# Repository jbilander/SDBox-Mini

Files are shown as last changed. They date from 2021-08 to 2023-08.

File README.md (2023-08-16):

# SDBox Mini for Amiga
SDBox in a standard DB25 plastic shell
***
Rev. 2B <br />
<a href="images/SDBox-mini_pic20.jpg">
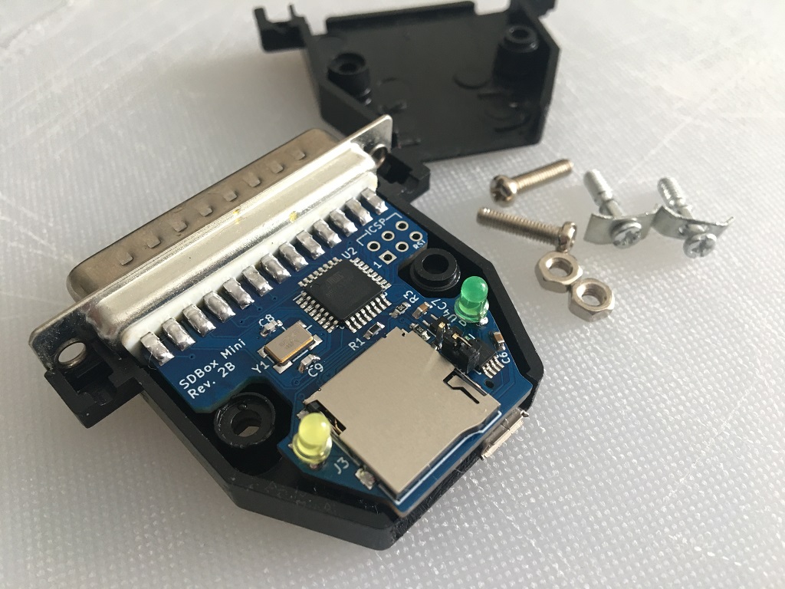
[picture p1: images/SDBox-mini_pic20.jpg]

</a>
<a href="images/SDBox-mini_pic21.jpg">
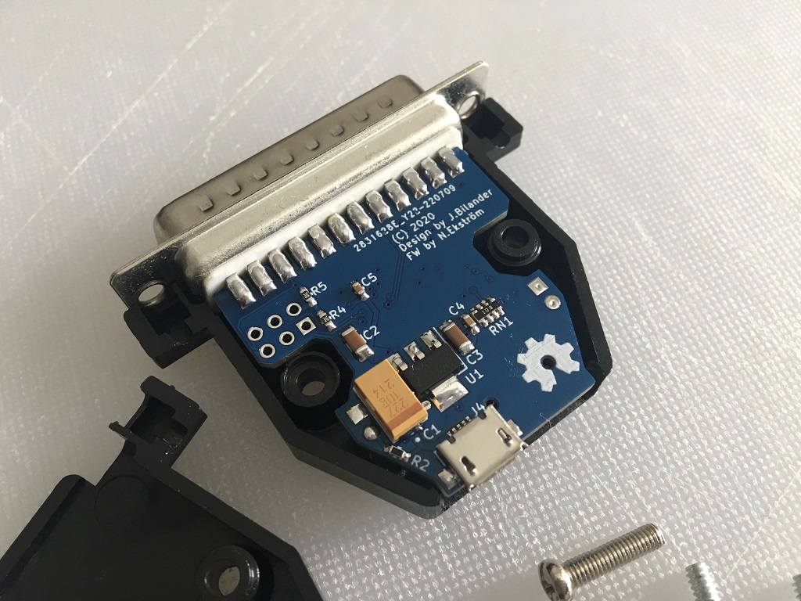
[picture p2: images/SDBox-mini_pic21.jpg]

</a>
<a href="images/SDBox-mini_pic22.jpg">
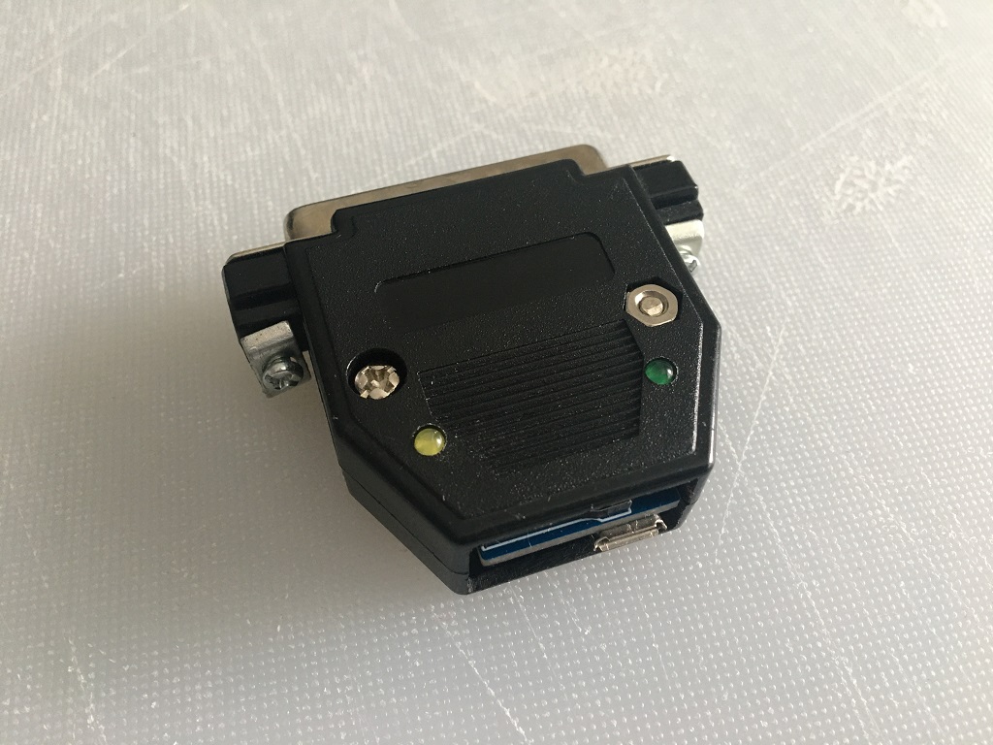
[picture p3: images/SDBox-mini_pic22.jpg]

</a>
<br />
Video:<br />
https://drive.google.com/file/d/1fLwmIyUeHZX4sln5bpJfz5QkDGD-QTOf/view?usp=sharing
<br />
<br />
+5V taken from floppy port with this USB-C dongle<br />
https://github.com/jbilander/Amiga_DB23_to_USB_C_power_only_adapter
***
Rev. 2A <br />
<a href="images/SDBox-mini_pic4.jpg">
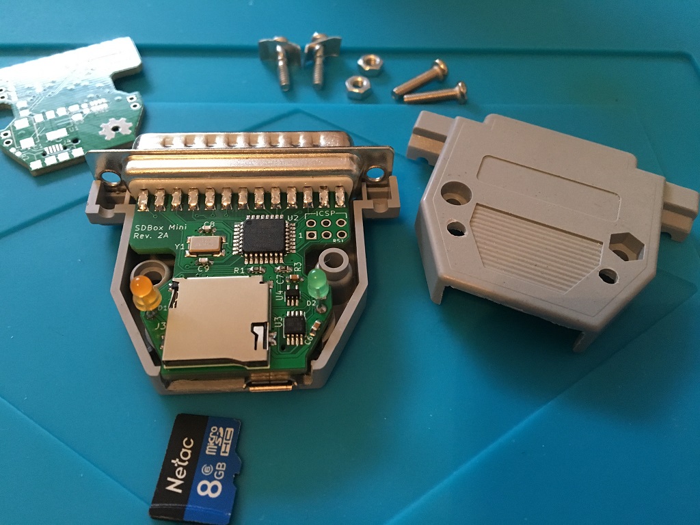
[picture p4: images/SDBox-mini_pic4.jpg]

</a>
<a href="images/SDBox-mini_pic5.jpg">
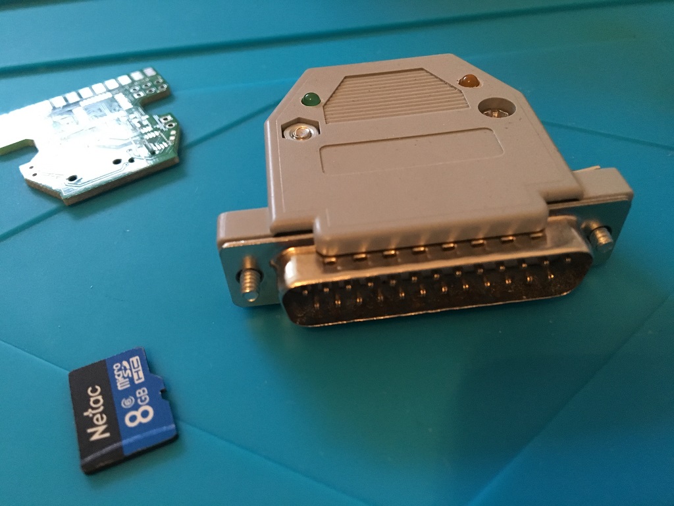
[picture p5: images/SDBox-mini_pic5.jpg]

</a>
<br />
<a href="images/SDBox-mini_pic1.png">
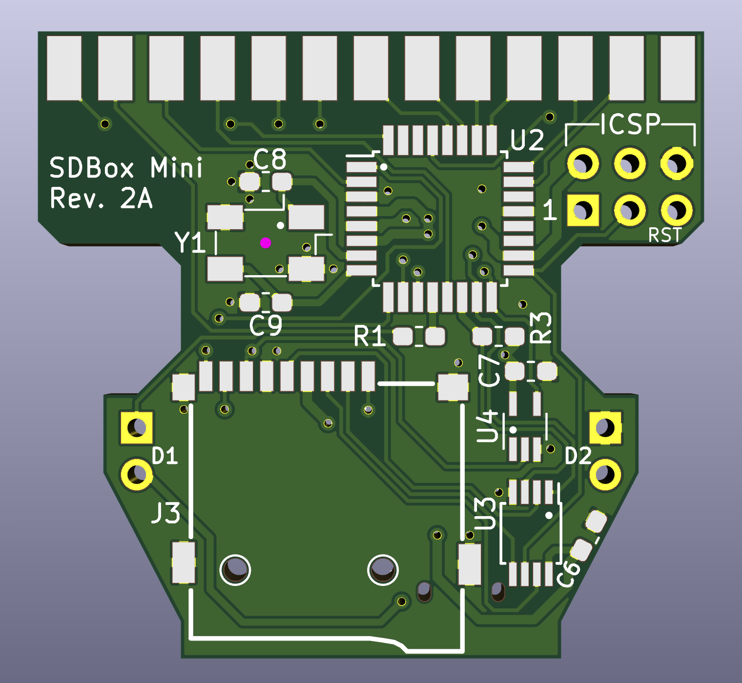
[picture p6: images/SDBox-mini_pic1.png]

</a>
<a href="images/SDBox-mini_pic2.png">
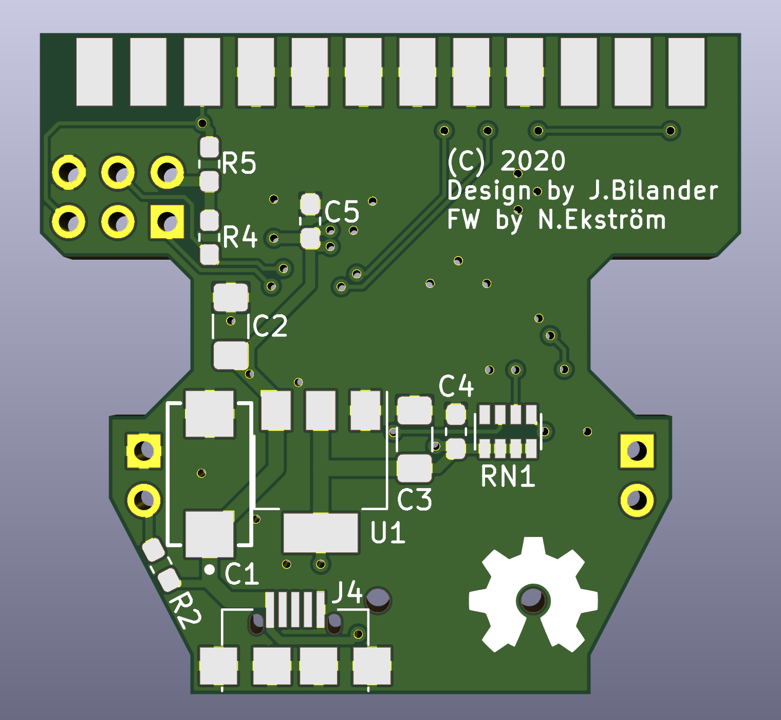
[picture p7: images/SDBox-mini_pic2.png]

</a>
<a href="images/SDBox-mini_pic3.png">
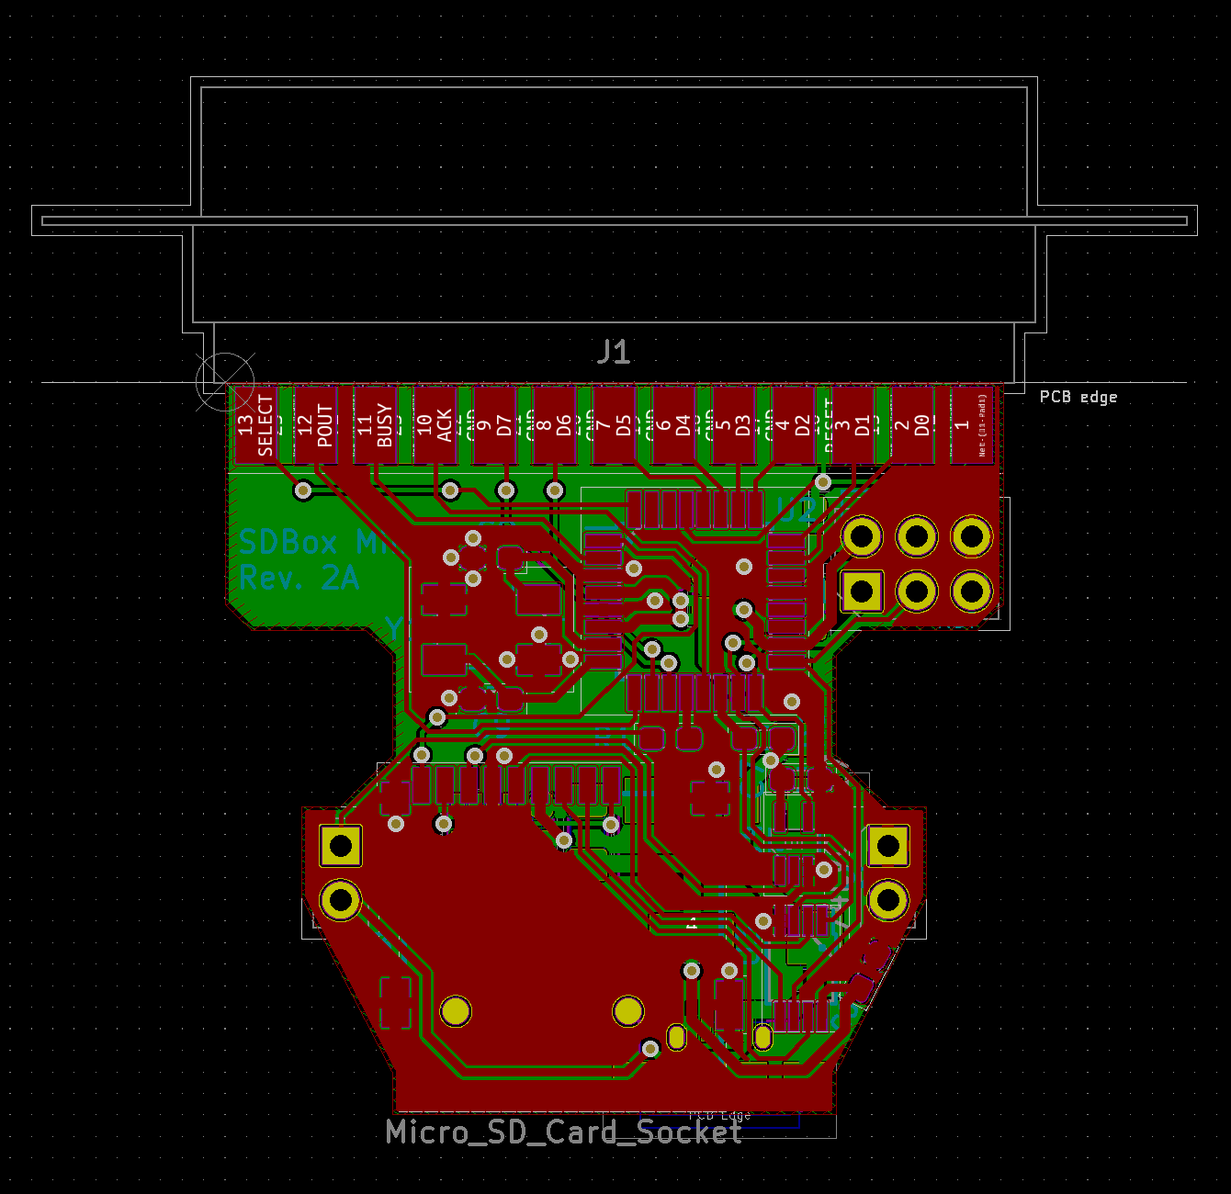
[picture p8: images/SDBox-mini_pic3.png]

</a>

***
This hardware uses the firmware written by Niklas Ekström, available here... <br />
https://github.com/niklasekstrom/amiga-par-to-spi-adapter

...or use my fork if you also want the Activity LED to blink (it also includes a batch-script `flashSDBoxMini.bat` for flashing the Mini) <br />
https://github.com/jbilander/amiga-par-to-spi-adapter

***
Connecting the Arduino to program the SDBox Mini

    (Programmer)
    Arduino as ISP - SDBox Mini 
    ------------------------------------
    D13 (SPI) SCK  - Pin 3 (ICSP) SCK
    D12 (SPI) MISO - Pin 1 (ICSP) MISO
    D11 (SPI) MOSI - Pin 4 (ICSP) MOSI
    D10 (SPI) SS   - Pin 5 (ICSP) /RESET
              5V   - Pin 2 VCC
              GND  - Pin 6 GND

On the Nano V3 the pins on the ICSP-header can be utilized connected like below. There is no need to solder an ICSP-header on the mini, you can just hold the connector against the footprint while programming.

<a href="images/connect_nano_ICSP_to_SDBox-mini.jpg">
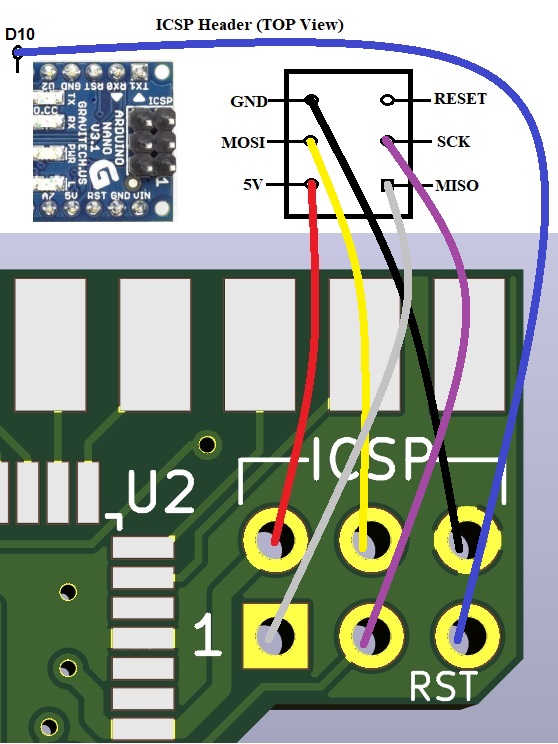
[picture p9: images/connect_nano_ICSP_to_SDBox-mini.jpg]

</a>
<a href="images/SDBox-mini_pic8.jpg">
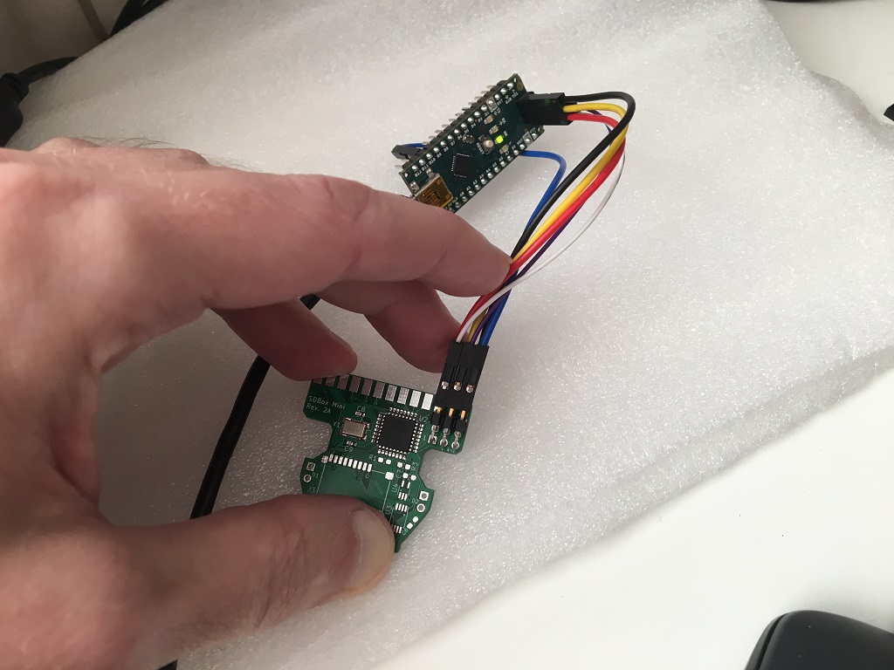
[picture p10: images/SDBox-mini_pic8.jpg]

</a>

***

To use the Arduino Nano as ISP it first has to be flashed with the ArduinoISP-sketch which is available under `File->Examples` in the Arduino IDE, or you can use the attached batch-script `flash_Arduino_as_ISP.bat` and binary hex `ArduinoISP.ino.arduino_standard.hex` I have put them in a zip-file under Releases `ArduinoISP.zip`. Alter the com port in the script file to suit your machine and execute it from a command-prompt. Now you are ready to flash the SDBox-Mini via the Arduino.

***

### Flash the SDBox Mini using the Arduino as ISP
This requires that you already have built the `main.hex` file in the `avr`-folder, then execute `flashSDBoxMini.bat` from a command prompt:
<details>
<summary>

    C:\Users\Jorgen\Projects\amiga-par-to-spi-adapter\avr>flashSDBoxMini.bat

</summary>

```
C:\Users\Jorgen\Projects\amiga-par-to-spi-adapter\avr>"C:\Program Files (x86)\Arduino\hardware\tools\avr/bin/avrdude" -C "C:\Program Files (x86)\Arduino\hardware\tools\avr/etc/avrdude.conf" -v -pm328p -cstk500v1 -PCOM4 -b19200 -Uflash:w:main.hex:i -Ulfuse:w:0xe6:m -Uhfuse:w:0xdf:m -Uefuse:w:0xfc:m

avrdude: Version 6.3-20190619
         Copyright (c) 2000-2005 Brian Dean, http://www.bdmicro.com/
         Copyright (c) 2007-2014 Joerg Wunsch

         System wide configuration file is "C:\Program Files (x86)\Arduino\hardware\tools\avr/etc/avrdude.conf"

         Using Port                    : COM4
         Using Programmer              : stk500v1
         Overriding Baud Rate          : 19200
         AVR Part                      : ATmega328P
         Chip Erase delay              : 9000 us
         PAGEL                         : PD7
         BS2                           : PC2
         RESET disposition             : dedicated
         RETRY pulse                   : SCK
         serial program mode           : yes
         parallel program mode         : yes
         Timeout                       : 200
         StabDelay                     : 100
         CmdexeDelay                   : 25
         SyncLoops                     : 32
         ByteDelay                     : 0
         PollIndex                     : 3
         PollValue                     : 0x53
         Memory Detail                 :

                                  Block Poll               Page                       Polled
           Memory Type Mode Delay Size  Indx Paged  Size   Size #Pages MinW  MaxW   ReadBack
           ----------- ---- ----- ----- ---- ------ ------ ---- ------ ----- ----- ---------
           eeprom        65    20     4    0 no       1024    4      0  3600  3600 0xff 0xff
           flash         65     6   128    0 yes     32768  128    256  4500  4500 0xff 0xff
           lfuse          0     0     0    0 no          1    0      0  4500  4500 0x00 0x00
           hfuse          0     0     0    0 no          1    0      0  4500  4500 0x00 0x00
           efuse          0     0     0    0 no          1    0      0  4500  4500 0x00 0x00
           lock           0     0     0    0 no          1    0      0  4500  4500 0x00 0x00
           calibration    0     0     0    0 no          1    0      0     0     0 0x00 0x00
           signature      0     0     0    0 no          3    0      0     0     0 0x00 0x00

         Programmer Type : STK500
         Description     : Atmel STK500 Version 1.x firmware
         Hardware Version: 2
         Firmware Version: 1.18
         Topcard         : Unknown
         Vtarget         : 0.0 V
         Varef           : 0.0 V
         Oscillator      : Off
         SCK period      : 0.1 us

avrdude: AVR device initialized and ready to accept instructions

Reading | ################################################## | 100% 0.07s

avrdude: Device signature = 0x1e950f (probably m328p)
avrdude: safemode: lfuse reads as E6
avrdude: safemode: hfuse reads as DF
avrdude: safemode: efuse reads as FC
avrdude: NOTE: "flash" memory has been specified, an erase cycle will be performed
         To disable this feature, specify the -D option.
avrdude: erasing chip
avrdude: reading input file "main.hex"
avrdude: writing flash (496 bytes):

Writing | ################################################## | 100% 0.68s

avrdude: 496 bytes of flash written
avrdude: verifying flash memory against main.hex:
avrdude: load data flash data from input file main.hex:
avrdude: input file main.hex contains 496 bytes
avrdude: reading on-chip flash data:

Reading | ################################################## | 100% 0.44s

avrdude: verifying ...
avrdude: 496 bytes of flash verified
avrdude: reading input file "0xe6"
avrdude: writing lfuse (1 bytes):

Writing | ################################################## | 100% 0.03s

avrdude: 1 bytes of lfuse written
avrdude: verifying lfuse memory against 0xe6:
avrdude: load data lfuse data from input file 0xe6:
avrdude: input file 0xe6 contains 1 bytes
avrdude: reading on-chip lfuse data:

Reading | ################################################## | 100% 0.02s

avrdude: verifying ...
avrdude: 1 bytes of lfuse verified
avrdude: reading input file "0xdf"
avrdude: writing hfuse (1 bytes):

Writing | ################################################## | 100% 0.02s

avrdude: 1 bytes of hfuse written
avrdude: verifying hfuse memory against 0xdf:
avrdude: load data hfuse data from input file 0xdf:
avrdude: input file 0xdf contains 1 bytes
avrdude: reading on-chip hfuse data:

Reading | ################################################## | 100% 0.02s

avrdude: verifying ...
avrdude: 1 bytes of hfuse verified
avrdude: reading input file "0xfc"
avrdude: writing efuse (1 bytes):

Writing | ################################################## | 100% 0.03s

avrdude: 1 bytes of efuse written
avrdude: verifying efuse memory against 0xfc:
avrdude: load data efuse data from input file 0xfc:
avrdude: input file 0xfc contains 1 bytes
avrdude: reading on-chip efuse data:

Reading | ################################################## | 100% 0.02s

avrdude: verifying ...
avrdude: 1 bytes of efuse verified

avrdude: safemode: lfuse reads as E6
avrdude: safemode: hfuse reads as DF
avrdude: safemode: efuse reads as FC
avrdude: safemode: Fuses OK (E:FC, H:DF, L:E6)

avrdude done.  Thank you.

C:\Users\Jorgen\Projects\amiga-par-to-spi-adapter\avr>

```
</details>

***

### Connecting a RPi4 to program the SDBox Mini

<br />
Warning!<br />
Connection of a GPIO to a voltage higher than 3.3V will likely destroy the GPIO block within the SoC.<br /><br />
I used my <a href="https://github.com/jbilander/Logic-level-converter-board">Logic level converter board</a> in between the devices and powered from the RPi's +5V 
<br />
<br />
<a href="images/SDBox-mini_RPi4-GPIO-Programming.jpg">
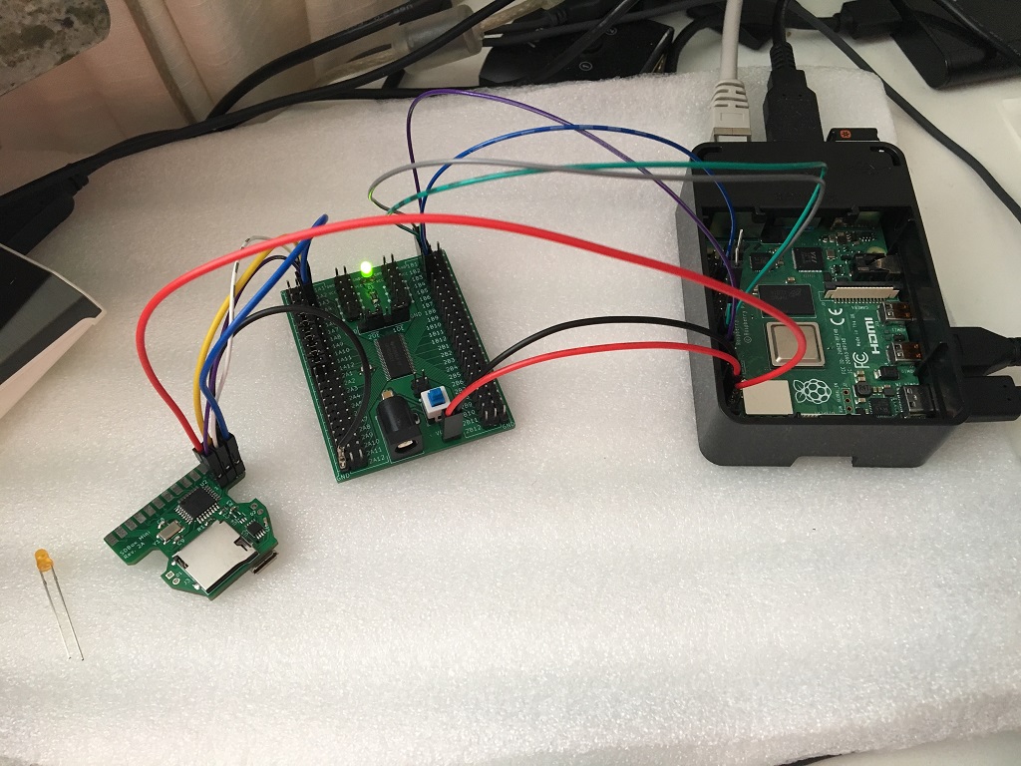
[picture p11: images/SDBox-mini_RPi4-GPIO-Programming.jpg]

</a>
<a href="images/RPi4-GPIO-Pinout.jpg">
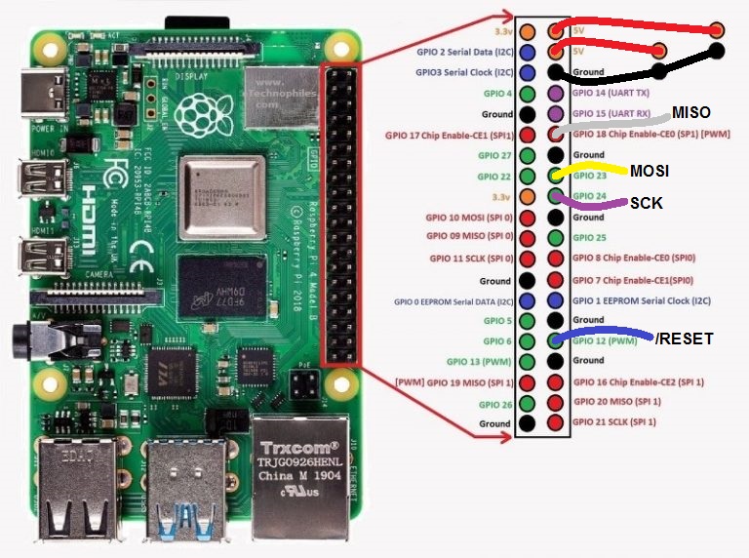
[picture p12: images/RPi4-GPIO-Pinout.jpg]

</a>
<br />
First install avrdude:

    sudo apt install avrdude

Now copy the default config file to a new file under /home/pi

    cp /etc/avrdude.conf ~/avrdude_gpio.conf
    
Add this entry last in the file using your editor (vim or nano) and save the file:

    #------------------------------------------------------------
    # Linux GPIO configuration for avrdude
    # Change the lines below to the GPIO pins connected to the AVR
    #------------------------------------------------------------
    programmer
        id        = "pi_1";
        desc      = "Use the Linux sysfs interface to bitbang GPIO lines";
        type      = "linuxgpio";
        reset     = 12;
        sck       = 24;
        mosi      = 23;
        miso      = 18;
    ;

Now cd into /home/pi and make the script-file executable:

    chmod 755 ./flashSDBoxMini.sh

With all jumper-wires connected and `main.hex` built, run the script `flashSDBoxMini.sh` (OR type the line below and hit enter)

    sudo avrdude -C ~/avrdude_gpio.conf -c pi_1 -v -p m328p -Uflash:w:main.hex:i -Ulfuse:w:0xe6:m -Uhfuse:w:0xdf:m -Uefuse:w:0xfc:m

<details>
<summary>

    pi@raspberrypi:~ $ ./flashSDBoxMini.sh

</summary>

```
avrdude: Version 6.3-20171130
         Copyright (c) 2000-2005 Brian Dean, http://www.bdmicro.com/
         Copyright (c) 2007-2014 Joerg Wunsch

         System wide configuration file is "/home/pi/avrdude_gpio.conf"
         User configuration file is "/root/.avrduderc"
         User configuration file does not exist or is not a regular file, skipping

         Using Port                    : unknown
         Using Programmer              : pi_1
         AVR Part                      : ATmega328P
         Chip Erase delay              : 9000 us
         PAGEL                         : PD7
         BS2                           : PC2
         RESET disposition             : dedicated
         RETRY pulse                   : SCK
         serial program mode           : yes
         parallel program mode         : yes
         Timeout                       : 200
         StabDelay                     : 100
         CmdexeDelay                   : 25
         SyncLoops                     : 32
         ByteDelay                     : 0
         PollIndex                     : 3
         PollValue                     : 0x53
         Memory Detail                 :

                                  Block Poll               Page                       Polled
           Memory Type Mode Delay Size  Indx Paged  Size   Size #Pages MinW  MaxW   ReadBack
           ----------- ---- ----- ----- ---- ------ ------ ---- ------ ----- ----- ---------
           eeprom        65    20     4    0 no       1024    4      0  3600  3600 0xff 0xff
           flash         65     6   128    0 yes     32768  128    256  4500  4500 0xff 0xff
           lfuse          0     0     0    0 no          1    0      0  4500  4500 0x00 0x00
           hfuse          0     0     0    0 no          1    0      0  4500  4500 0x00 0x00
           efuse          0     0     0    0 no          1    0      0  4500  4500 0x00 0x00
           lock           0     0     0    0 no          1    0      0  4500  4500 0x00 0x00
           calibration    0     0     0    0 no          1    0      0     0     0 0x00 0x00
           signature      0     0     0    0 no          3    0      0     0     0 0x00 0x00

         Programmer Type : linuxgpio
         Description     : Use the Linux sysfs interface to bitbang GPIO lines
         Pin assignment  : /sys/class/gpio/gpio{n}
           RESET   =  12
           SCK     =  24
           MOSI    =  23
           MISO    =  18

avrdude: AVR device initialized and ready to accept instructions

Reading | ################################################## | 100% 0.00s

avrdude: Device signature = 0x1e950f (probably m328p)
avrdude: safemode: lfuse reads as E6
avrdude: safemode: hfuse reads as DF
avrdude: safemode: efuse reads as FC
avrdude: NOTE: "flash" memory has been specified, an erase cycle will be performed
         To disable this feature, specify the -D option.
avrdude: erasing chip
avrdude: reading input file "main.hex"
avrdude: writing flash (496 bytes):

Writing | ################################################## | 100% 0.11s

avrdude: 496 bytes of flash written
avrdude: verifying flash memory against main.hex:
avrdude: load data flash data from input file main.hex:
avrdude: input file main.hex contains 496 bytes
avrdude: reading on-chip flash data:

Reading | ################################################## | 100% 0.10s

avrdude: verifying ...
avrdude: 496 bytes of flash verified
avrdude: reading input file "0xe6"
avrdude: writing lfuse (1 bytes):

Writing | ################################################## | 100% 0.00s

avrdude: 1 bytes of lfuse written
avrdude: verifying lfuse memory against 0xe6:
avrdude: load data lfuse data from input file 0xe6:
avrdude: input file 0xe6 contains 1 bytes
avrdude: reading on-chip lfuse data:

Reading | ################################################## | 100% 0.00s

avrdude: verifying ...
avrdude: 1 bytes of lfuse verified
avrdude: reading input file "0xdf"
avrdude: writing hfuse (1 bytes):

Writing | ################################################## | 100% 0.00s

avrdude: 1 bytes of hfuse written
avrdude: verifying hfuse memory against 0xdf:
avrdude: load data hfuse data from input file 0xdf:
avrdude: input file 0xdf contains 1 bytes
avrdude: reading on-chip hfuse data:

Reading | ################################################## | 100% 0.00s

avrdude: verifying ...
avrdude: 1 bytes of hfuse verified
avrdude: reading input file "0xfc"
avrdude: writing efuse (1 bytes):

Writing | ################################################## | 100% 0.00s

avrdude: 1 bytes of efuse written
avrdude: verifying efuse memory against 0xfc:
avrdude: load data efuse data from input file 0xfc:
avrdude: input file 0xfc contains 1 bytes
avrdude: reading on-chip efuse data:

Reading | ################################################## | 100% 0.00s

avrdude: verifying ...
avrdude: 1 bytes of efuse verified

avrdude: safemode: lfuse reads as E6
avrdude: safemode: hfuse reads as DF
avrdude: safemode: efuse reads as FC
avrdude: safemode: Fuses OK (E:FC, H:DF, L:E6)

avrdude done.  Thank you.

pi@raspberrypi:~ $

```
</details>

***

### Caveats

One caveat to keep in mind when building and programming Rev.2A (the first revision of the Mini) is the flashing of the fw can't be done with U4 chip in place as it drives/conflicts with MISO on ICSP (In-Circuit Serial Programming). For Rev. 2B PCB use 74AHCT1G126 instead of 74LVC1G17, same package/footprint. This solves the flashing conflict problem. You put a Jumper-shunt on JP1 (on Rev 2B PCB) while flashing and remove it afterwards.

***

### Building SDBox Mini

Start with the 16 MHz Crystal, C8, C9 and the ATMega328P. 

<a href="images/SDBox-mini_pic6.jpg">
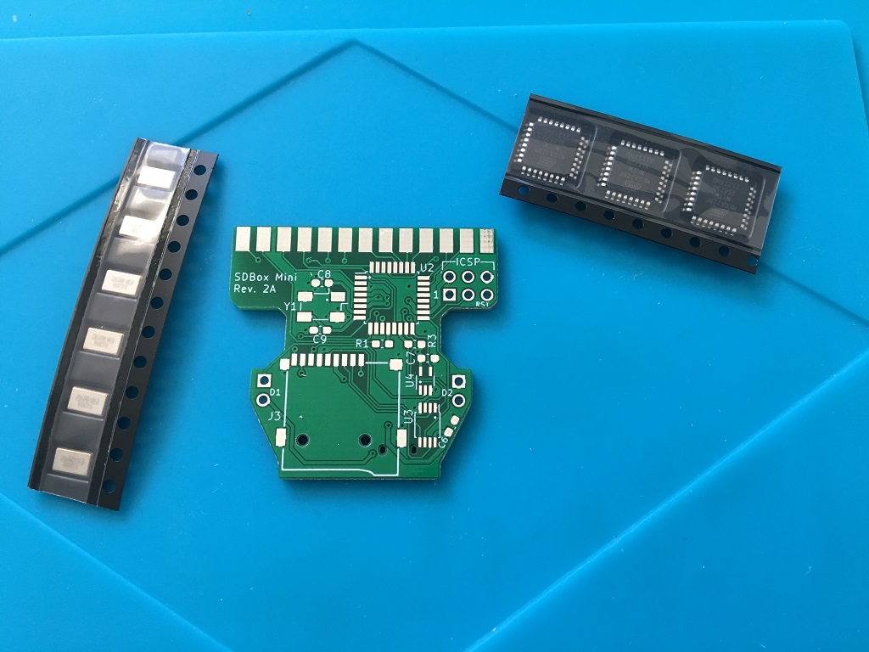
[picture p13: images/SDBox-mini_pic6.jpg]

</a>
<a href="images/SDBox-mini_pic7.jpg">
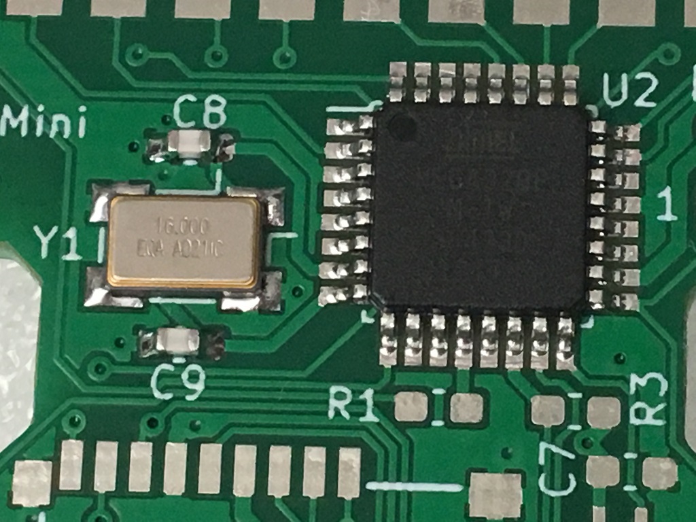
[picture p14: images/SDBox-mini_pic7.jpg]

</a>

***

At this point you should be able to flash the Firmware to the ATMega using either an Arduino as ISP or a Raspberry Pi.<br /><br />

Continue with the rest of the components on the front side, and then the back side. I usually pre-tin the C1 pads and use hot air to put the C1-Capacitor in place.
***

<a href="images/SDBox-mini_pic9.jpg">
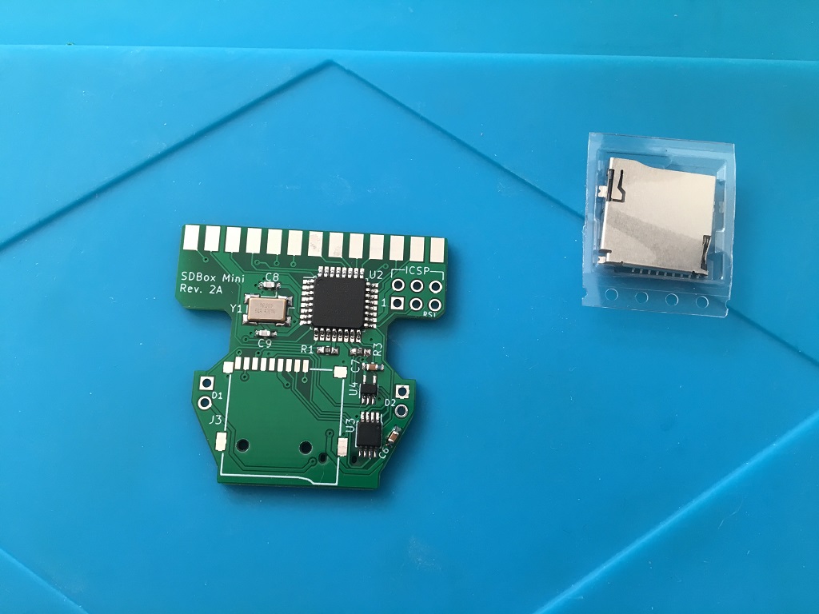
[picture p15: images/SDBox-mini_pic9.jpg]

</a>
<a href="images/SDBox-mini_pic10.jpg">
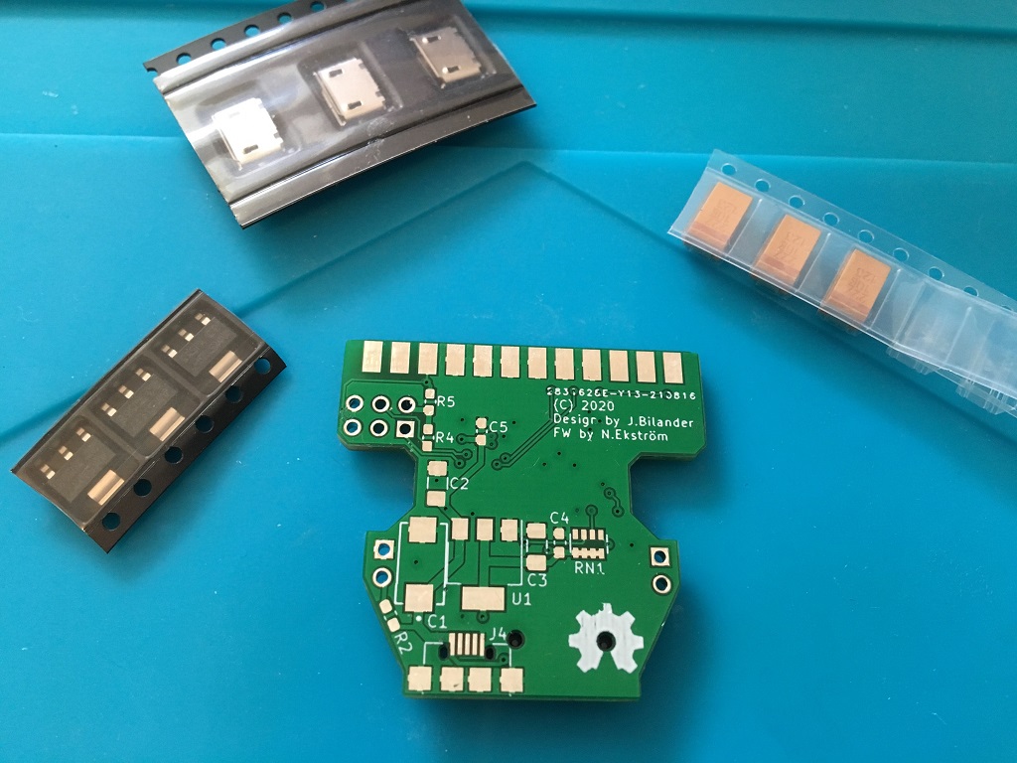
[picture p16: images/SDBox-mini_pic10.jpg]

</a>
<a href="images/SDBox-mini_pic11.jpg">
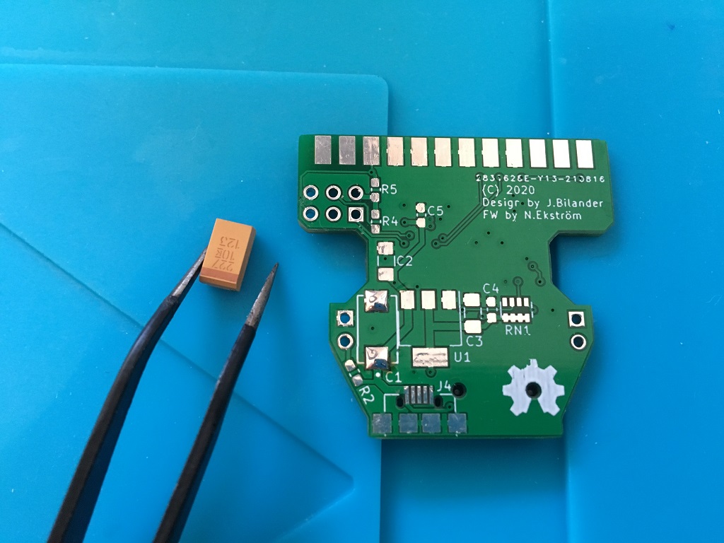
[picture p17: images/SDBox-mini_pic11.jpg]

</a>

***

Verify the Micro USB-jack and the voltage levels...

***

<a href="images/SDBox-mini_pic12.jpg">
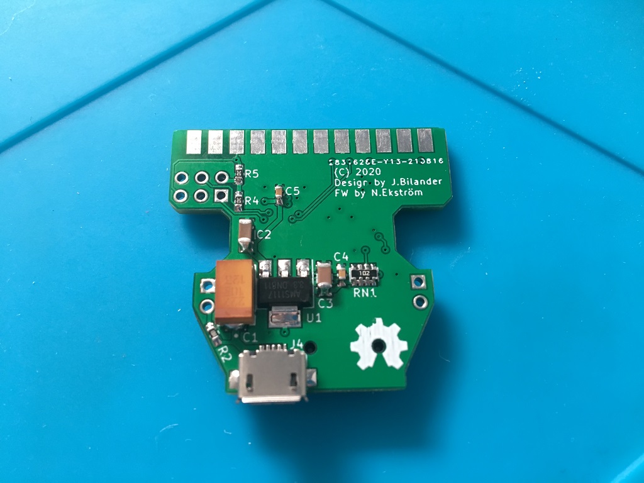
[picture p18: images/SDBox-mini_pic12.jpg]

</a>
<a href="images/SDBox-mini_pic13.jpg">
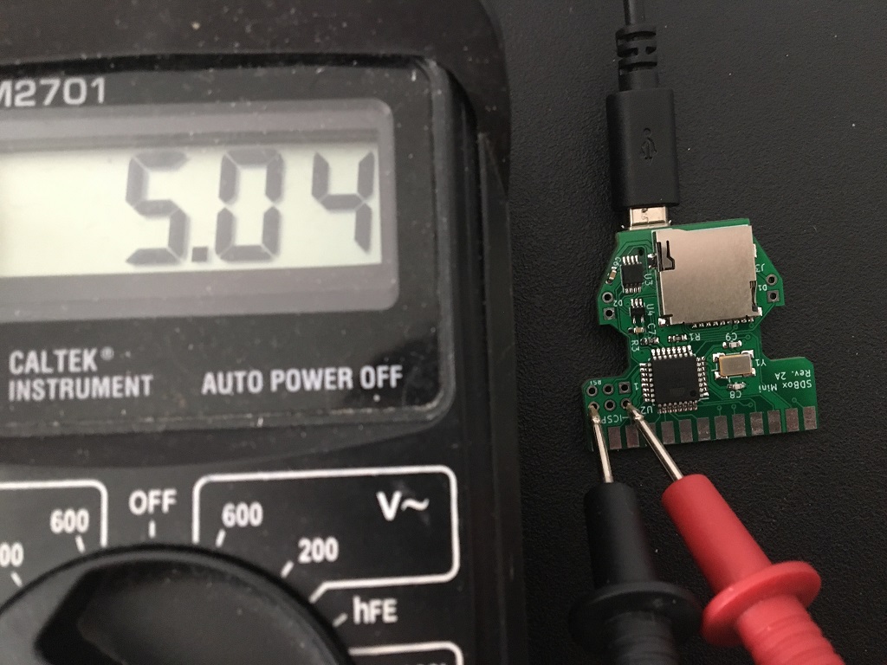
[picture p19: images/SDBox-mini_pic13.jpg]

</a>
<a href="images/SDBox-mini_pic14.jpg">
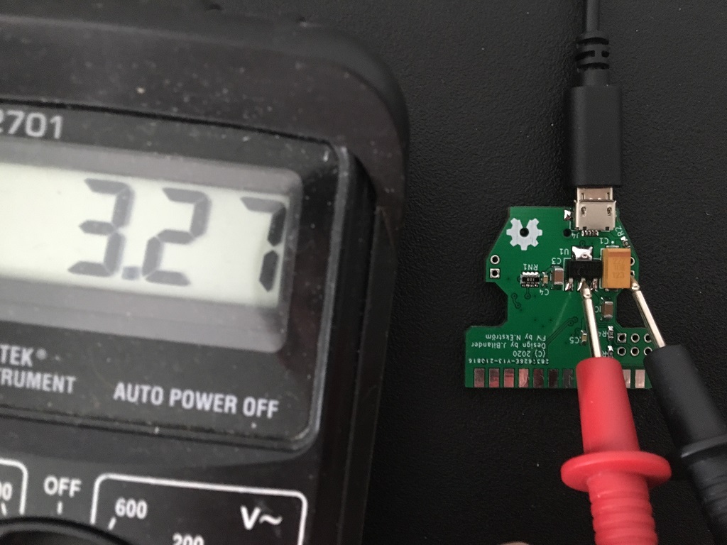
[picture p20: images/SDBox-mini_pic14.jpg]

</a>

***

Now it's time to drill the holes for the LEDs, begin with a 1 mm drill and then step up to 2 mm and finally 3 mm. Be very careful when drilling to get a nice clean 3mm hole, it's very easy to slip and the hole gets oval or offset.

***

<a href="images/SDBox-mini_pic15.jpg">
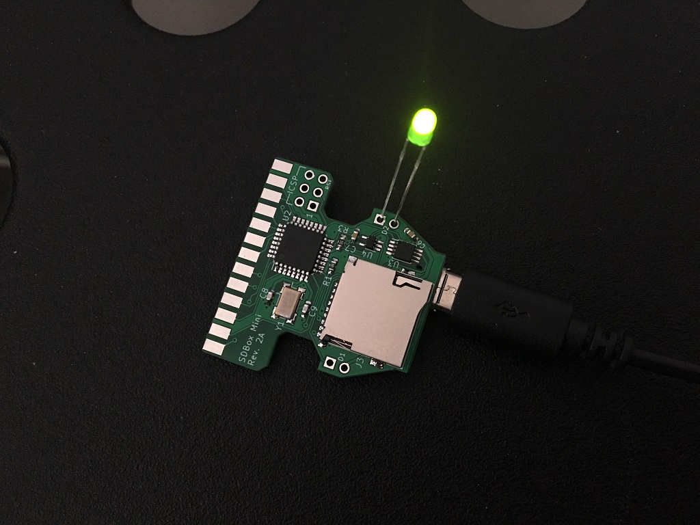
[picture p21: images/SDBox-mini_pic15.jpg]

</a>
<a href="images/SDBox-mini_pic16.jpg">
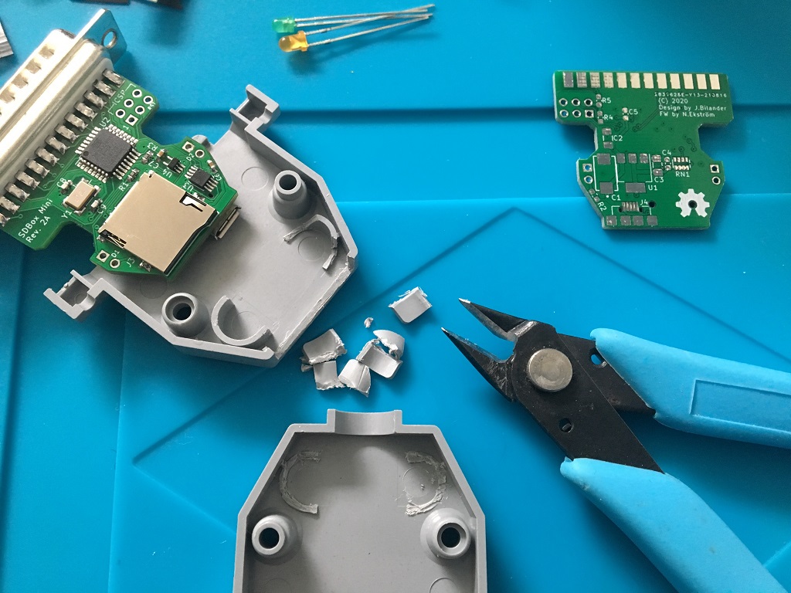
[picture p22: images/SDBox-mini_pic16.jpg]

</a>
<a href="images/SDBox-mini_pic17.jpg">
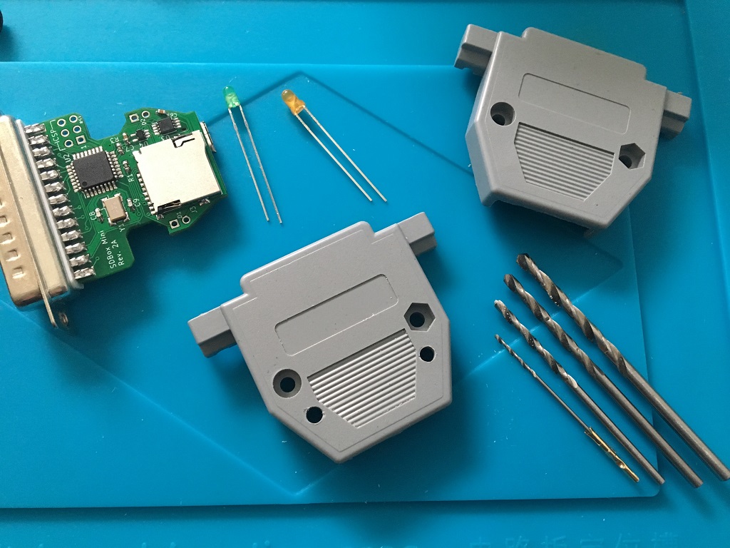
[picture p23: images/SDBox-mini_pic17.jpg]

</a>

***

Short video showing copying a 8 MB file from the HD to the SD-card on my A1200. +5V to power the SDBox I nicked from the floppy port DB23->microUSB (Howto make such a cable <a href="https://github.com/jbilander/SDBox-v2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">here</a> ).
<br />
Video:<br />
https://i.imgur.com/mF9Bp4C.mp4

***

<a href="images/SDBox-mini_pic4.jpg">

</a>
<a href="images/SDBox-mini_pic18.jpg">
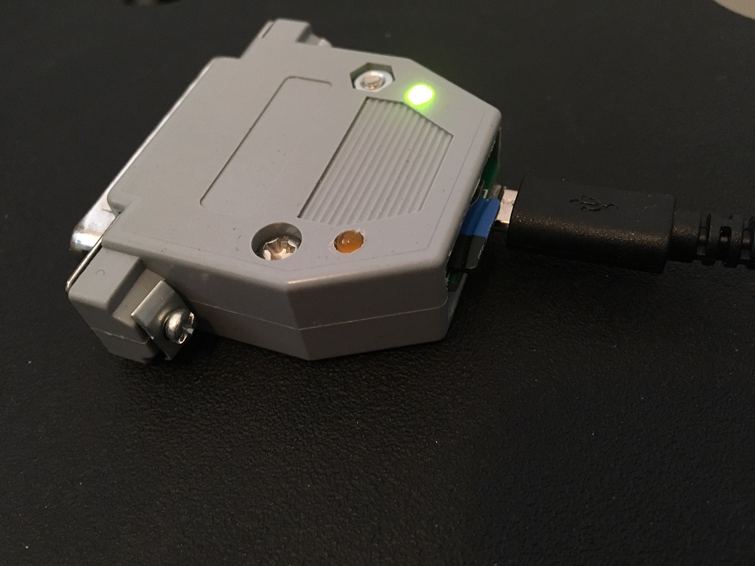
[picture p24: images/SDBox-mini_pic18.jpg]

</a>
<a href="images/SDBox-mini_pic19.jpg">
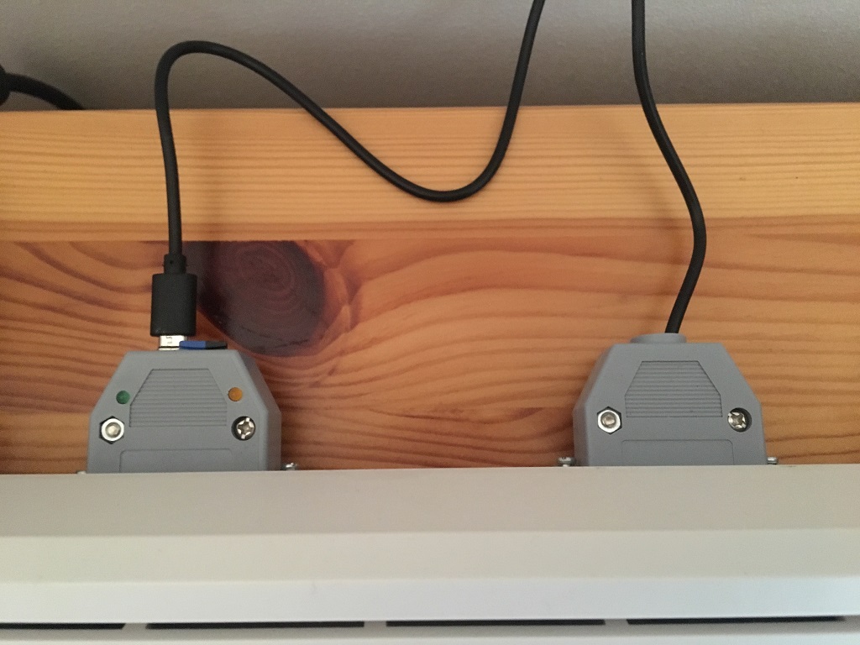
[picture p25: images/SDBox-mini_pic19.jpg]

</a>

***

### Amiga installation:

Download `Amiga.zip` from Releases.

* Put latest `fat95` into `L:`  (download from Aminet)
* Put `SD0` and `SD0.info` into `Devs:`  (from `Amiga.zip`)
* Put `spisd.device` into `Devs:` (from `Amiga.zip`)
* Put `Mount_SDCARD` and `Mount_SDCARD.info` anywhere on your HD or floppy disk.
* Put a FAT/FAT32 formatted MicroSD-card in the card reader (Max 4 GB partitioned).
* Double-click the `Mount_SDCARD` icon.

Disk icon should now appear on the Workbench screen.

***

Happy Hackin´

***
BOM Rev. 2B  (Same as 2A with the addition)
---------
Position  | Name/Value   | Package | Notes
-|-|-|-|
U4 | 74AHCT1G126 | 5-TSSOP, SC-70-5, SOT-353  (2.0 mm × 1.25mm) | Single non-inverting buffer 74AHCT1G126 (instead of 74LVC1G17) https://www.mouser.com/ProductDetail/Nexperia/74AHCT1G126GW125?qs=P62ublwmbi%252BsCpFPoi5fgw%3D%3D 
JP1 | 2.0mm two-pin header + jumper-shunt | |
R6 | 10k Ohm Resistor | 0603 SMD | Pull-up resistor for OE pin 1 of 74AHCT1G126

***

BOM Rev. 2A
---------
Position  | Name/Value   | Package | Notes
-|-|-|-|
U1 | LM1117-3.3 | SOT-223 | Low-Dropout Linear Regulator 3.3 Volt
U2 | ATMega328P-AU | TQFP-32_7x7mm_P0.8mm | 8-bit AVR Microcontroller with 32K Bytes In-System Programmable Flash
U3 | 74LVC3G17 | TSSOP-8_3x3mm_P0.65mm | Triple non-inverting Schmitt trigger with 5V tolerant input https://www.digikey.se/product-detail/en/nexperia-usa-inc/74LVC3G17DP-125/1727-5998-1-ND/2753830
U4 | 74LVC1G17 | 5-TSSOP, SC-70-5, SOT-353  (2.0 mm × 1.25mm) | Single non-inverting Schmitt trigger https://www.digikey.se/product-detail/en/nexperia-usa-inc/74LVC1G17GW-125/1727-4117-1-ND/1965408 For Rev. 2B PCB use 74AHCT1G126 instead of 74LVC1G17, same package/footprint: https://www.mouser.com/ProductDetail/Nexperia/74AHCT1G126GW125?qs=P62ublwmbi%252BsCpFPoi5fgw%3D%3D
J1 | D-Sub DB25 | DB25 Male connector with solder lugs | DB25 for Amiga parallel port
J2 | ICSP | PinHeader_2x03_P2.54mm_Vertical | Pin header _(MISO,VCC,SCK,MOSI,/RESET,GND)_ for flashing AVR via In-Circuit Serial Programming
J3 | Micro SD Card Holder | 9-pin Micro SD card slot connector | https://www.aliexpress.com/item/32802051702.html
J4 | Micro USB connector | USB Micro B SMT | For +5V Power only <br />https://www.aliexpress.com/item/32991869539.html
Y1 | Ceramic SMD quartz 16.0 MHz, LC 12 pF | 3 x 5 x 1 mm | For use with XTAL1, XTAL2 on AVR, e.g. https://www.reichelt.com/se/en/ceramic-smd-quartz-3-x-5-x-1-mm-16-0-mhz-16-000000-mj-p85005.html <br /> or <br /> https://www.mouser.se/ProductDetail/520-160-12-30B-AGMT
D1 (Optional) | LED 3mm | PinHeader_1x02_P2.54mm_Vertical, pin pitch 2.54 mm | SD Activity LED indicator, Diffused Orange / Amber, 1.8V-2.3V, 20-30 mA, 605-610nm
D2 (Optional) | LED 3mm | PinHeader_1x02_P2.54mm_Vertical, pin pitch 2.54 mm | Power LED indicator, Green Diffused T-1, 25 mcd, 565 nm, 2.2 V, 25 mA
R1 (Optional) | 150 Ohm Resistor | 0603 SMD, 200 mW | (Mandatory if D1 populated) Series resistor for D1 LED, adjust R-value to your type of LED and preferred brightness
R2 (Optional) | 150 Ohm Resistor | 0603 SMD, 200 mW | (Mandatory if D2 populated) Series resistor for D2 LED, adjust R-value to your type of LED and preferred brightness
R3 | 10k Ohm Resistor | 0603 SMD | Pull-up (to VCC) resistor for /SS
R4 (Optional) | 10k Ohm Resistor | 0603 SMD | Pull-up (to VCC) resistor for MOSI
R5 (Optional) | 10k Ohm Resistor | 0603 SMD | Pull-up (to VCC) resistor for /RESET
RN1 | CAY16-103J4LF RES ARRAY 4 Resistors 10k | 1206 SMD | https://www.digikey.se/product-detail/sv/bourns-inc/CAY16-103J4LF/CAY16-103J4LFCT-ND/
RN1 | | | Pull-up (to 3V3) for MISO_3V3
RN1 | | | Pull-up (to 3V3) for DAT1 pin 8 on MicroSD-holder
RN1 | | | Pull-up (to 3V3) for DAT2 pin 1 on MicroSD-holder
C1 | 220uF Capacitor | SMD-Tantalum, 4.3 x 7.3 x 2.8 mm | Capacitor for VIN +5V Power via USB https://www.reichelt.com/se/en/smd-tantalum-220-f-10v-125-c-t491d-220u-10-p206492.html
C2 | 10uF Capacitor | 1206 SMD | Capacitor (VCC) for Voltage regulator U1
C3 | 10uF Capacitor | 1206 SMD | Capacitor (3V3) for Voltage regulator U1
C4 | 0.1uF = 100nF Capacitor | 0603 SMD | Capacitor (3V3) for Voltage regulator U1
C5 | 0.1uF = 100nF Capacitor | 0603 SMD | Decoupling capacitor for U2
C6 | 0.1uF = 100nF Capacitor | 0603 SMD | Decoupling capacitor for U3
C7 | 0.1uF = 100nF Capacitor | 0603 SMD | Decoupling capacitor for U4
C8 | 16pF Capacitor | 0603 SMD | Capacitor for XTAL1 (Y1)
C9 | 16pF Capacitor | 0603 SMD | Capacitor for XTAL2 (Y1)
X | D-Sub DB25 | Two DB25 plastic shells with screws and nuts | Plastic hood cover x 2

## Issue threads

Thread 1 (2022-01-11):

Writing errors

Knuckles112, 2022-01-11:
First of all, thank you for this project. I assambled 2 boards flashing your firmware but I get errors writing to the SD (I have tried with various brands and partitions), reading is fine. Any ideas?
P.S. Tested on A500 and A1200

jbilander, 2022-01-11:
Hi, That's strange. I haven't seen any write errors on my A500 nor A1200. What is your configuration in terms of KS-version and WB? I have only tested on KS/WB 1.3 and 3.1 on A500/A1200. You can check/verify your CIA timings is ok with ATK (AmigaTestKit), link below:
https://github.com/keirf/Amiga-Stuff/releases

Things you could check if you have a logic analyser or oscilloscope:
Check logic levels on the D0-D7, SELECT, BUSY, POUT -lines. Perhaps pull-ups could/should be added.

I think VIH -- Minimum INPUT Voltage level to be considered a HIGH is 0.6*VCC equals around 3V on the ATMega328 when VCC is 5V.
https://learn.sparkfun.com/tutorials/logic-levels/all#arduino-logic-levels

Knuckles112, 2022-01-18:
Hello. I have already made all the measurements with the oscilloscope. Attached are the measurements taken on the Atmel in "MISO" and "MOSI" lines when there is read/write activity.
All other signals are HI at 5V and LO at 0V, but "MOSI" is the suspect because of its form.
I have already tried several different ATMEGA328 and ATMEGA328P with the same result.
All the resistors and components are installed, I have also tried without the optional pullups with the same result.
When I want to copy something from the Amiga to the SD I always get write errors and practically nothing is written to the SD.
MISO:
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
MOSI:
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

Thank you in advance.

niklasekstrom, 2022-01-18:
Interesting.

How fast can your oscilloscope sample signals (what is the max frequency)?

Do you have an accelerator in the A500?

Knuckles112, 2022-01-18:
-How fast can your oscilloscope sample signals (what is the max frequency)?
200Mhz / 1GSa/s
-Do you have an accelerator in the A500?
Yes, a TF534 but with the original processor and loading drivers from floppy I obtain the same write errors.
I have also tried it with an Amiga 1200, I always get the same writing problem.

niklasekstrom, 2022-01-18:
Can you zoom in more on the MOSI signal? The SPI bus should switch at 8 MHz, so the cycle time is 125 ns.

And perhaps measure both before and after U3?

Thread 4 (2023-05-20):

"Bad Number" issue

youenchene, 2023-05-20:
Hi,

Tx a lot for your work.

I just solder my first SDBox Mini and trying to make it work. (rev2b)

I compiled the firmware from this source : https://github.com/jbilander/amiga-par-to-spi-adapter/blob/master/avr/main.c

I compiled it from my mac using vscode using platformio extension :

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

Converted to hex :

> avr-objcopy -O ihex ../.pio/build/uno/firmware.elf  main.hex

And flashed the firmware :

> avrdude -cttl232r -pm328p -P /dev/tty.usbserial-AB7ADN6F -v -Uflash:w:main.hex:i -Ulfuse:w:0xe6:m -Uhfuse:w:0xdf:m -Uefuse:w:0xfc:m

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

Used the amiga.zip from there https://github.com/jbilander/SDBox-Mini/releases/download/v2a/Amiga.zip

(workbench 3.2.2)

And got the "Bad Number" error :

> SD0:
> Bad Number (well in french on my screen)

I checked the voltage from your documentation and they are not the same  (extra power supply ):

- **6.45v instead of 5v**
- **4.55v instead of 3.3v**

I rechecked all soldering and resistors.

Any idea to dig in?

jbilander, 2023-05-20:
Hi, voltage levels are way to high. Check your power supply, try a different one. Maybe best is to take +5V from the Amigas floppy drive port pin 12.

Take the latest _spisd.device_ from link below, also you can try with the _main.hex_ from there but it doesn't have the activity LED blinking but should work.

https://github.com/niklasekstrom/amiga-par-to-spi-adapter/releases

youenchene, 2023-05-20:
Update on voltage : I change the battery fo my voltmeter. It's the right voltage now.

youenchene, 2023-05-21:
Ok, I did the test 3 times to be sure :

-  ✅ working well with the 2.2 release you ask to test : https://github.com/niklasekstrom/amiga-par-to-spi-adapter/releases
- ❌ "Bad Number" on the one I compiled from your github.

jbilander, 2023-05-21:
Hi, probably it has to do with your compilation then because the code is identical to Niklas' repo except for driving the LED:

https://github.com/niklasekstrom/amiga-par-to-spi-adapter/commit/aeaf351bd57fc0b75dae18e1f8b91ef14cbc8c00

You can try and build using the script and the avrdude from Arduino IDE, like I did:

https://github.com/jbilander/SDBox-v2/blob/main/images/SDBox-v2_flashing_Nano_pic4.jpg

youenchene, 2023-05-21:
Why do you not just share the compiled .hex in a release?

(And also for testing purpose, would be better to have known working .hex)

Le dim. 21 mai 2023 à 11:33, Jorgen Bilander ***@***.***> a
écrit :

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

jbilander, 2023-05-21:
Because in order to flash the device you need the avr-toolchain (with avrdude) installed anyway and it's just one script to run to generate the file before flashing, pretty simple.
And people expect everything to be served on a silver platter, well this is a DIY-project.

youenchene, 2023-05-21:
Well I am a software developer too (more high level language).

I know it’s DIY.

I am just a « little » stubborn when there is a bug.

Here it can be :
 - my compilation tool chain
 - software issue
 - soldering issue

If I can eliminate on the hypothesis (compilation tool chain) it can be
great!

Le dim. 21 mai 2023 à 13:20, Jorgen Bilander ***@***.***> a
écrit :

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

jbilander, 2023-05-21:
I tried building with the latest and it generated the same hex (attached)

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
[main.zip](https://github.com/jbilander/SDBox-Mini/files/11524517/main.zip)

youenchene, 2023-05-21:
Back,

This main.hex is working but no blinking.

We agree that the + of the LED on the bottom on the led hole? (parallel
port on the top).

Le dim. 21 mai 2023 à 14:09, Jorgen Bilander ***@***.***> a
écrit :

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

jbilander, 2023-05-21:
Hi, you can look in the KiCAD...it is open source, perhaps you have accidentally put the LED with wrong orientation or the resistor is missing or too high value? Should be a 200 Ohm resistor or thereabout.

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

youenchene, 2023-05-21:
150 ohm resistor and LED in the right direction (and working). I'll reinvestigate on the second one. (got 5 minimum pcb from pcbway you know.)

It's a silver version, it should work 😉

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

jbilander, 2023-05-21:
Hi, try it without the shell on, it might be that the shell touches something (the LED leg) and shorts it out. I think those silver shells conducts electricity and since it holds the DB23-connector it gets grounded. Just to rule it out.

youenchene, 2023-05-21:
I tested it before the shell.

The shell is just plastic.

Le dim. 21 mai 2023 à 19:29, Jorgen Bilander ***@***.***> a
écrit :

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

youenchene, 2023-08-26:
Hi, go time to get back to the issue, now fully working with yourf firmware with the orange led blinking on sdcard activity.

The issue was ... a bad/broken 250 ohm resistor.

Closed 2023-08-26.

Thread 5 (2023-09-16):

Not a DOS Disk in device SD0

youenchene, 2023-09-16:
Hi again,

Just need help on debugging.

I have one SDBox Mini working well.

I built 2 other one.

With the same amiga software, same SDCard and same firmware as the first working one on the 2 new ones I've got the this **Not a DOS Disk** error (french translating, i've got the message in french).

The orange LED is blinking when you insert the SD.

The error happen when you mount.

I've check all soldering, all resistor and all chips, all sounds OK.

Would be open to any clue on where to look.

Cheers again for your work.

jbilander, 2023-09-16:
Hi, check that you have activity on the MOSI- and MISO-lines with a logic analyzer or oscope, compare with a working one, you might have a faulty IC or something. Also check the generated 16 MHz CLK looks good. And double-check soldering and pull-ups. Also you could try with the new driver that has Patrik's bugfix for better sd-card support, but since you are testing with a known good card it shouldn't be the culprit.
Here is a link to the latest spisd.device:
https://github.com/niklasekstrom/amiga-par-to-spi-adapter/pull/9

youenchene, 2023-09-17:
New spisd.device test : same issue

I have to borrow a oscilloscope now.

jbilander, 2023-09-17:
ok, yeah that was expected. If this is a Rev. 2B you are building I would suspect U4 (74AHCT1G126) is faulty or you forgot to remove the jumper after programming so MISO-signal is not working as it should, or perhaps the firmware wasn't programmed correctly. With Rev 2A you need to program the AVR before soldering down the 74LVC1G17 as it will otherwise interfere with the programming done via the ICSP-header, this problem was corrected in 2B.

drphilxr, 2023-12-12:
I bought the SDBOX in 2022 from amigastore.eu and have the **exact same problem**
"Not a DOS disk" - tried FAT and FAt32 formats, reinstalled the SD0: files, the spisd.device (from the github, latest), and the 'Mount_SDCARD' icon does mount SD):- just not a dos disk!
im at my wits end. Tried on multiple A500's, from OS 2-3.2

jbilander, 2023-12-13:
@drphilxr Them selling the product as a commercial item and then pawning off support to the community if something doesn't work is absolutely not good.

drphilxr, 2023-12-13:
Yes agree completely- Amigastore.eu used to reply to emails about purchased products with support- not anymore. What can I say but its probably a uSD card issue, as per commentary here/elsewhere. Thankyou for hosting support questions!

jbilander, 2023-12-13:
@drphilxr Did you try with the latest spisd.device from link on comment 2 above, thanks to Patrik the driver is more compatible with different MicroSD-cards. What you also could try is to put pull-up resistors on the Data-lines. We have seen on A3000 there is a need for pull-ups on the data-lines.
https://github.com/jbilander/sdbox/issues/18#issuecomment-1830798423

drphilxr, 2023-12-13:
@jbilander thankyou for that; don't use sdbox on the A3000 now after investing $$ in a ZZ9000 card. But still need SDBox on an A500! So yeah using the same SD card (formatted Fat32- which Amigastore.eu states will work on their product page!)- and spisd.device v2- still "not a dos disk". Will of course try to format this card, and new ones on the way, with FAT (fat95) and see what happens. It's a journey...

jbilander, 2023-12-13:
@drphilxr No problem, I think it's best if you do the formatting on a PC like this:
https://github.com/jbilander/SDBox-Mini/issues/2#issuecomment-1221970894
The 4GB restriction is no longer in play since Patrik's bugfix, but you might wanna keep it small(er) anyway because a larger partition takes more memory in AmigaOS.

drphilxr, 2023-12-13:
So- did run CMD as admin, and disk part to clean (like cleaning the CF cards of old!), and did FAT formatting on a new 2Gb card.
SPISD.device v2 installed in devs:, with SD0. WB 2.1.
And.... 'Not a DOS disk" :(
The SDBox was working before on another A500. Time to ask Amigastore.eu if i can get a refund? Wish me luck - lol.
thankyou for your time also

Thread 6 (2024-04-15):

Almost working, but not quite...

RetepV, 2024-04-15:
Hi Jorgen!

I created an SDBox Mini 2b, but am running in a bit of trouble and maybe you can help.

First of all, I should say two things:

1. I am using the SDBox Mini on a commodore CDTV. Shouldn't be a problem, I think. I burned a cdrom with all the necessary stuff. WB 1.3.3.
2. When I ordered, I apparently ordered ATMEGA328PB instead of ATMEGA328P (wasn't careful enough). And this might be the root of the issues.

I doublechecked all solderings, and they seem fine.

I have installed all of the necessary drivers on the cdrom. I have a 4GBSD card, formatted with only one 2GB partition, FAT32 with 4096 bytes allocation size.

So far, no magic smoke.

However, when I boot the CDTV and select Mount_SDCARD, I see the IconX window appear, and I see the yellow light on the SDBox  turn on. But then the IconX window just hangs there forever.

Any hints on where I should start looking?

As said, I used an ATMEGA328PB, and they are not the same as an ATMEGA328P. A few pins are reassigned, and the clock circuit is different. I was wondering if you had ever tried to use an ATMEGA328PB, as the ATMEGA328P was unobtainable for some time.

RetepV, 2024-04-15:
Hmm, a follow up. Something that I did not try was to call Mount_SDCARD while there was no SD card plugged in. I just did that, and got the message "No  disk present in unit 0". So something is at least working. :)

Plugging in an SD card however, hangs everything again. Neither Retry nor Cancel button on the system request do anything, except change colour back and forth.

jbilander, 2024-04-15:
Hi, I don't know the details about the PB-version. I know it's not a drop in replacement, but I know also that Sukkopera got version 1 of SDBox working with it. He rebuilt the firmware hex.

https://github.com/jbilander/sdbox/issues/14

Did you try that? if not look here
https://github.com/jbilander/SDBox-v2/blob/main/images/SDBox-v2_flashing_Nano_pic4.jpg

and change to the right target mcu in the script files.
https://github.com/jbilander/amiga-par-to-spi-adapter/tree/master/avr

RetepV, 2024-04-16:
Thanks for the pointers! Let’s see how that goed. I didn’t think of having to recompile for the PB version, but in hindsight I guess it makes sense.

I’m checking out the code as well, so I can do some debugging. I’ll report back later!

RetepV, 2024-07-21:
Well, I wasn’t able to spend much time on it lately, but did do the following:

* updated all scripts to compile for atmega328pb and uploaded it to the device. But the problem stayed. I could mount from CLI, but when I did `list sd0:`, the yellow led came on but didn’t flicker and everything hung.

Then in desperation, I just purchased some atmega328p’s and built another sdbox mini, now with the recommended cpu (and fresh copy of the firmware source, just in case).

But, to my surprise it behaved exactly the same!

So I became suspicious that maybe it wasn’t the SDBOX but the Amiga (it’s a CDTV).

Then I remembered that, even though that CDTV was working fine, a diagnostics run once told me that one of the CIA’s had an issue (tod running slow or something).

So just to rule out everything, I exchanged the CIA’s. The CDTV booted fine. But lo and behold, the new SDBOX actually worked!

Then I connected the other SDBOX withe atmega328pb, and that $@@&$)@ device worked as well!

So it was the Amiga, in the end! Djeez!

And I should probably find a new CIA too, because I guess there will be other things that are not working so great.

Thanks for your help anyway, even though we were barking up the wring tree! I appreciate it that you took the time to give me the bunch of information. In any case, I can confirm that a 328PB will work fine, if the FW is compiled with the right options and flags.

RetepV, 2024-07-21:
Just a few images, including my mess. ;)

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

https://github.com/user-attachments/assets/05f232b7-83d3-4150-8d1a-a2e8dfa04313

RetepV, 2024-07-21:
One of the CIAs is definitely giving issues. After swapping the CIAs, if I run SysInfo, the system reboots 2 seconds after the program started. So, up for a new CIA.

jbilander, 2024-07-22:
> Thanks for your help anyway, even though we were barking up the wring tree! I appreciate it that you took the time to give me the bunch of information. In any case, I can confirm that a 328PB will work fine, if the FW is compiled with the right options and flags.

No problem, I'm glad you got it resolved in the end. And thanks for leaving the feedback...it may be useful to others facing the same problem. Yes the CIAs are known to be one of the parts that goes bad first in an Amiga, they seem more susceptible to damage than the other custom chips. Luckily you can still source replacements for reasonable money, although in later years the price has gone up significantly. Good thing replacement projects of the chip are in the works (to recreate it fully in a FPGA). For example here:
https://github.com/daglem/reDIP-CIA

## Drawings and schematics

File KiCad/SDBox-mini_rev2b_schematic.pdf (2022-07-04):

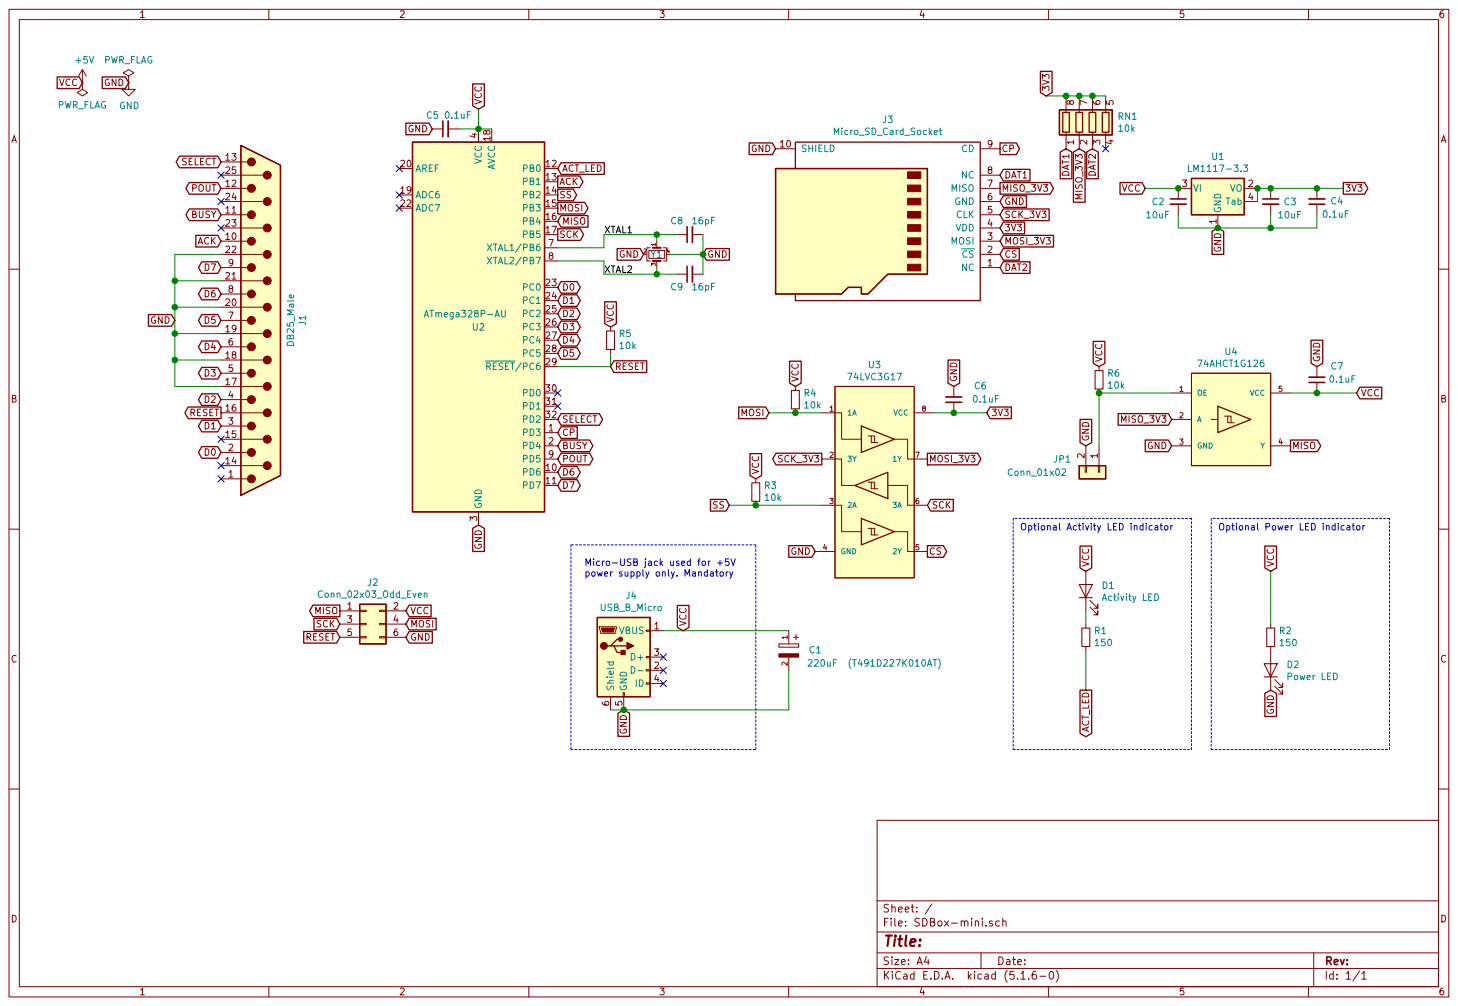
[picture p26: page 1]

Micro-USB jack used for +5V
power supply only. Mandatory

Id: 1/1 Title: File: SDBox-mini.sch Sheet: /

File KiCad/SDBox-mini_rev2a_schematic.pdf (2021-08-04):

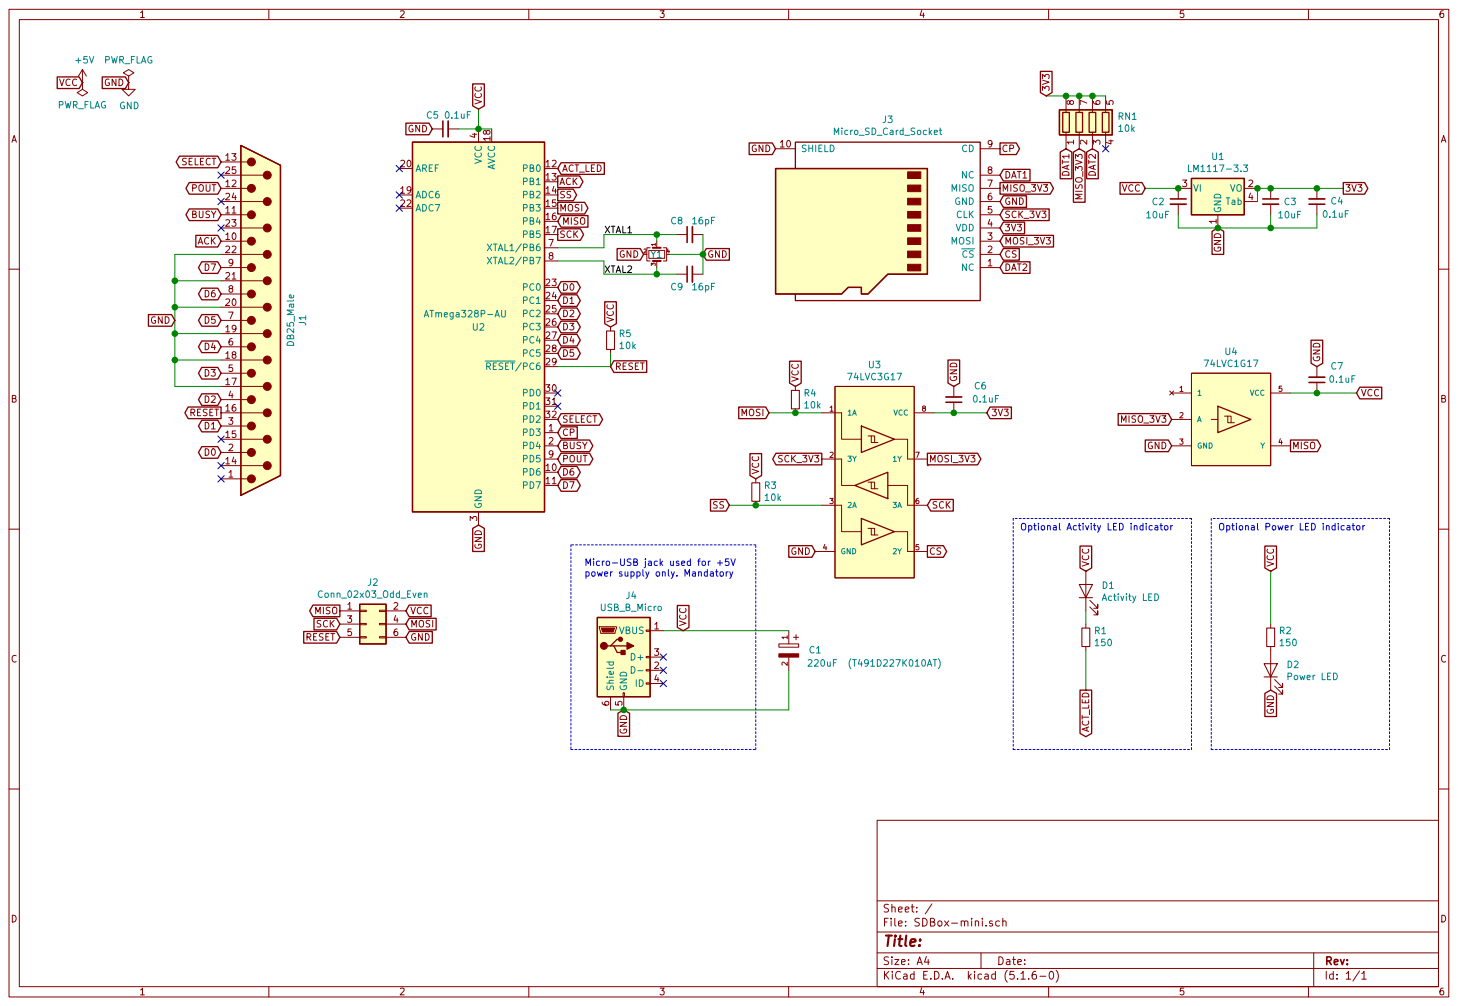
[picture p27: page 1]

power supply only. Mandatory

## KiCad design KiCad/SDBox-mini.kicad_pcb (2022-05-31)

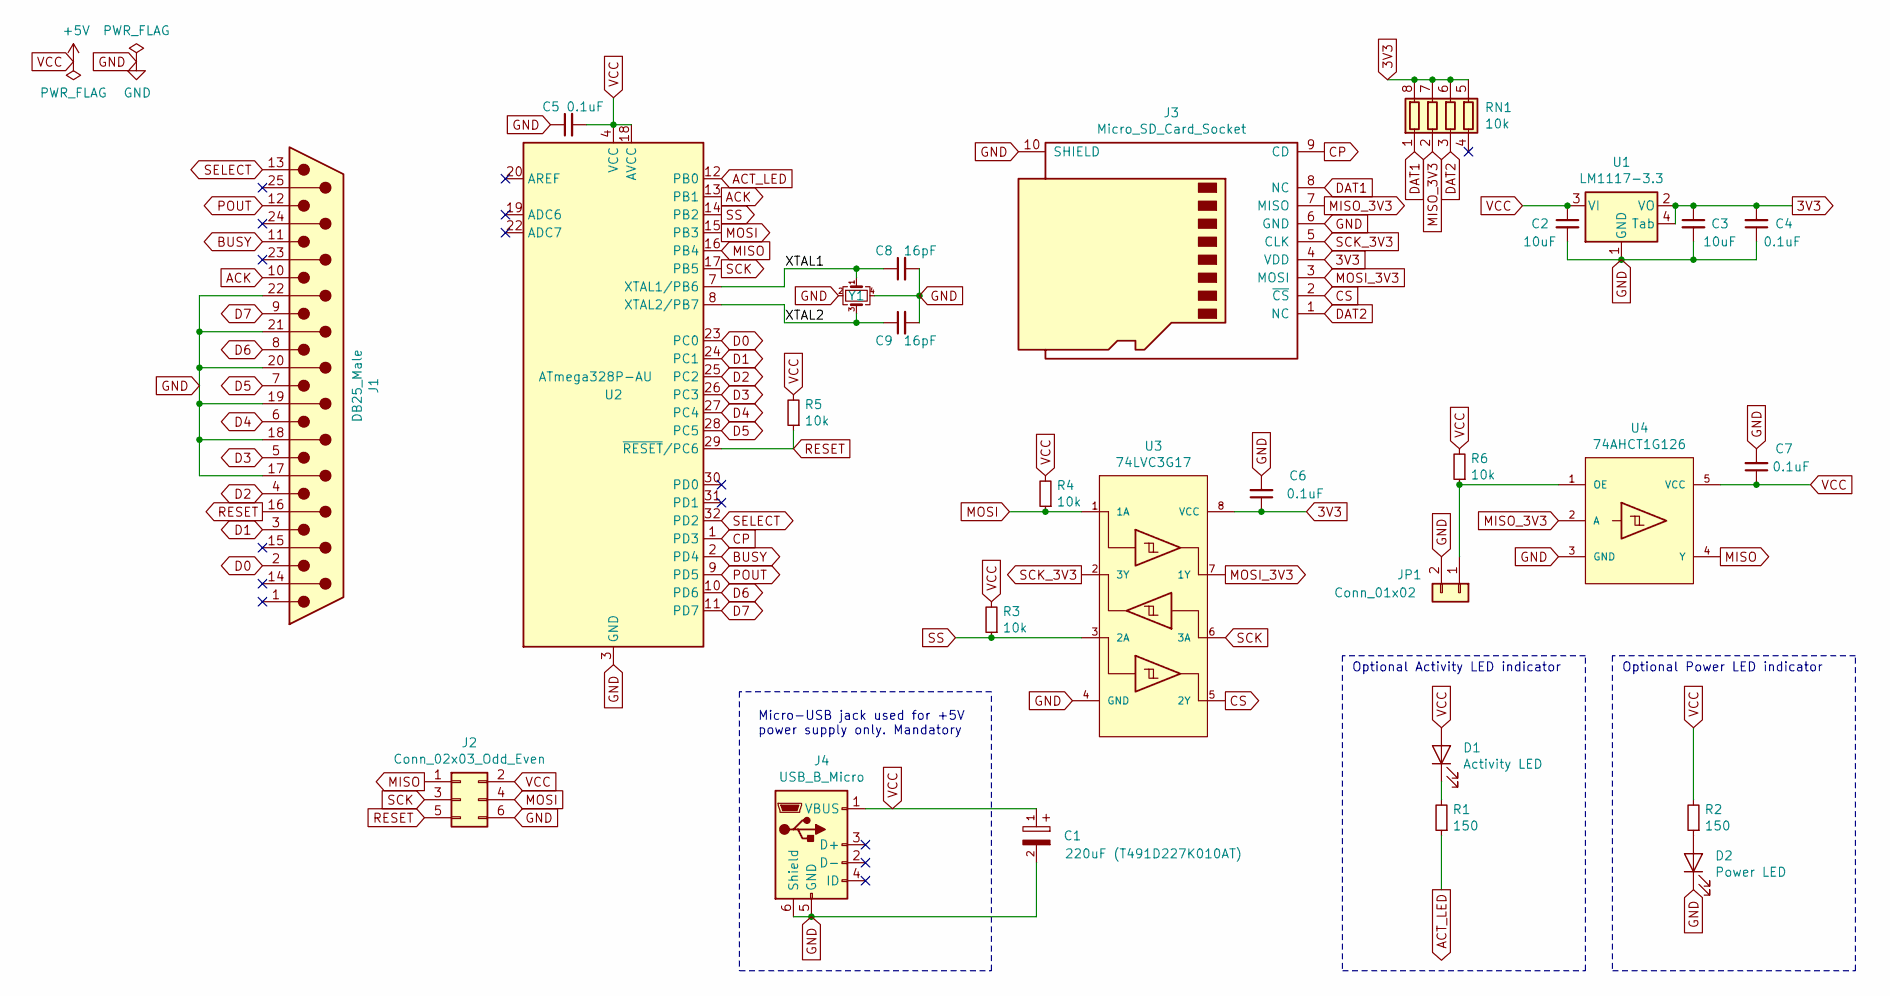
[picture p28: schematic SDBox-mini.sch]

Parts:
C1: 220uF (T491D227K010AT); CAPMP7343X430N
C2, C3: 10uF; C_1206_3216Metric_Pad1.42x1.75mm_HandSolder
C4, C5, C6, C7: 0.1uF; C_0603_1608Metric_Pad1.05x0.95mm_HandSolder
C8, C9: 16pF; C_0603_1608Metric_Pad1.05x0.95mm_HandSolder
D1: Activity LED; PinHeader_1x02_P2.54mm_Vertical
D2: Power LED; PinHeader_1x02_P2.54mm_Vertical
J1: DB25_Male; DSUB-25_Male_EdgeMount_P2.77mm
J2: Conn_02x03_Odd_Even; PinHeader_2x03_P2.54mm_Vertical
J3: Micro_SD_Card_Socket; GCT-MEM2055-00-190-01-A
J4: USB_B_Micro; USB_Micro-B_Unknown_5s_SMT
JP1: Conn_01x02; PinHeader_1x02_P2.00mm_Vertical
R1, R2: 150; R_0603_1608Metric_Pad1.05x0.95mm_HandSolder
R3, R4, R5, R6: 10k; R_0603_1608Metric_Pad1.05x0.95mm_HandSolder
RN1: 10k; RESCAF80P320X160X60-8N
U1: LM1117-3.3; SOT-223
U2: ATmega328P-AU; TQFP-32_7x7mm_P0.8mm
U3: 74LVC3G17; TSSOP-8_3x3mm_P0.65mm_Custom_Handsoldering
U4: 74AHCT1G126; SOT-353_SC-70-5_Custom_Handsoldering
Y1: Crystal_GND24_Small; Crystal_EuroQuartz_SMD_4Pin_5.0x3.2mm

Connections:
3V3: C3.1, C4.2, C6.1, J3.4 (VDD), RN1.5 (R4.2), RN1.6 (R3.2), RN1.7 (R2.2), RN1.8 (R1.2), U1.2 (VO), U1.4 (Tab), U3.8 (VCC)
/XTAL1: C8.1, U2.7 (XTAL1/PB6), Y1.1
/XTAL2: C9.1, U2.8 (XTAL2/PB7), Y1.3
ACK: J1.10, U2.13 (PB1)
ACT_LED: R1.1, U2.12 (PB0)
BUSY: J1.11, U2.2 (PD4)
CP: J3.9 (CD), U2.1 (PD3)
CS: J3.2 (~CS), U3.5 (2Y)
D0: J1.2, U2.23 (PC0)
D1: J1.3, U2.24 (PC1)
D2: J1.4, U2.25 (PC2)
D3: J1.5, U2.26 (PC3)
D4: J1.6, U2.27 (PC4)
D5: J1.7, U2.28 (PC5)
D6: J1.8, U2.10 (PD6)
D7: J1.9, U2.11 (PD7)
DAT1: J3.8 (NC), RN1.1 (R1.1)
DAT2: J3.1 (NC), RN1.3 (R3.1)
GND: C1.2, C2.2, C3.2, C4.1, C5.1, C6.2, C7.2, C8.2, C9.2, D2.1 (K), J1.17, J1.18, J1.19, J1.20, J1.21, J1.22, J2.6, J3.6 (GND), J3.10 (SHIELD), J4.5 (GND), J4.6 (Shield), JP1.2, U1.1 (GND), U2.3 (GND), U2.5 (GND), U2.21 (GND), U3.4 (GND), U4.3 (GND), Y1.2, Y1.4
MISO: J2.1, U2.16 (PB4), U4.4 (Y)
MISO_3V3: J3.7 (MISO), RN1.2 (R2.1), U4.2 (A)
MOSI: J2.4, R4.1, U2.15 (PB3), U3.1 (1A)
MOSI_3V3: J3.3 (MOSI), U3.7 (1Y)
unnamed: D1.1 (K), R1.2
unnamed: D2.2 (A), R2.1
unnamed: JP1.1, R6.1, U4.1 (OE)
POUT: J1.12, U2.9 (PD5)
RESET: J1.16, J2.5, R5.1, U2.29 (~RESET~/PC6)
SCK: J2.3, U2.17 (PB5), U3.6 (3A)
SCK_3V3: J3.5 (CLK), U3.2 (3Y)
SELECT: J1.13, U2.32 (PD2)
SS: R3.1, U2.14 (PB2), U3.3 (2A)
VCC: C1.1, C2.1, C5.2, C7.1, D1.2 (A), J2.2, J4.1 (VBUS), R2.2, R3.2, R4.2, R5.2, R6.2, U1.3 (VI), U2.4 (VCC), U2.6 (VCC), U2.18 (AVCC), U4.5 (VCC)

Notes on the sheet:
Optional Activity LED indicator
Optional Power LED indicator
Micro-USB jack used for +5V power supply only. Mandatory

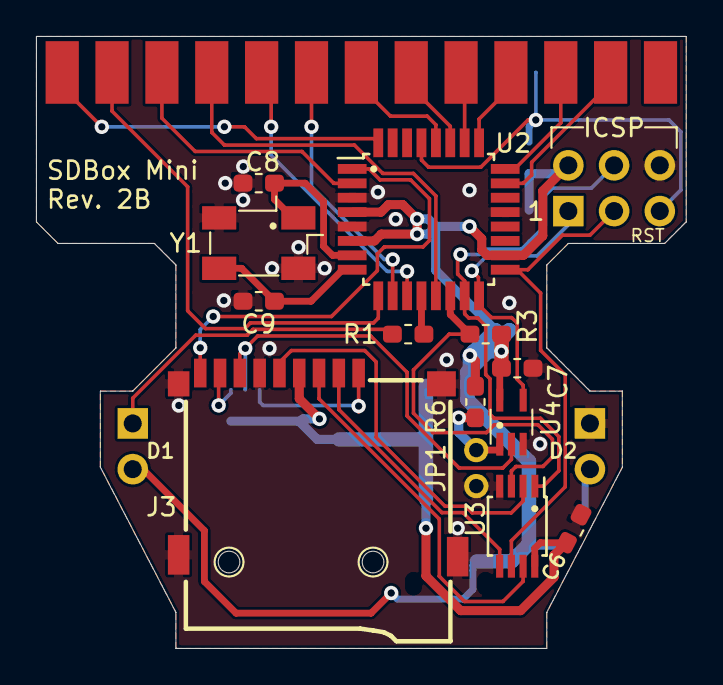
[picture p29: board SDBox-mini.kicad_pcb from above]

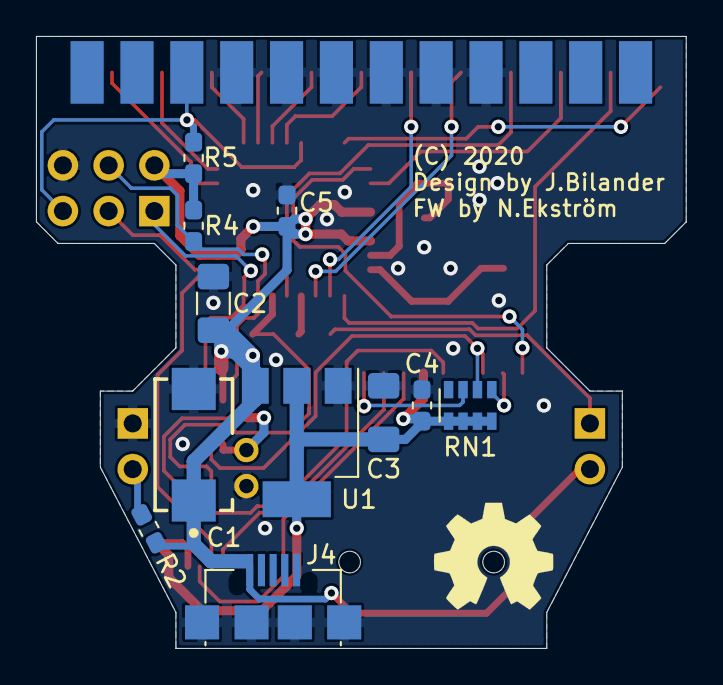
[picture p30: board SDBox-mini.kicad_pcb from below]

Board: 2 copper layers, 36.1 x 34.0 mm, 28 parts (11 on the bottom side), 33 nets.

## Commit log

2021-07-18 added KiCad files
    [SDBox-mini.kicad_pcb, SDBox-mini.sch]
2021-07-18 added MicroSD footprint
2021-07-18 resized PCB and added some components
    [SDBox-mini.kicad_pcb, SDBox-mini.sch]
2021-07-19 made custom crystal smd footprint 5.0x3.2mm
2021-07-19 added 3V3 voltage regulator, added 74LVC125A buffer
    [SDBox-mini.kicad_pcb, SDBox-mini.sch]
2021-07-19 added FTDI header
    [SDBox-mini.kicad_pcb, SDBox-mini.sch]
2021-07-19 changed to 74LVC3G17
    [SDBox-mini.kicad_pcb, SDBox-mini.sch]
2021-07-20 added USB micro jack, and Dual non-inverting Schmitt trigger, and debounce circuit for card detect
    [SDBox-mini.kicad_pcb, SDBox-mini.sch]
2021-07-20 adapted for new pinout and rerouted
    [SDBox-mini.kicad_pcb, SDBox-mini.sch]
2021-07-21 imporved routing and small fix of micro-usb footprint
    [SDBox-mini.kicad_pcb]
2021-07-21 reshaped PCB outline to accomodate LED indicators
    [SDBox-mini.kicad_pcb, SDBox-mini.sch]
2021-07-22 added footprint for smd tantalum cap T491D227K010AT
2021-07-22 added final caps, completed positioning of components and routing done
    [SDBox-mini.kicad_pcb, SDBox-mini.sch]
2021-07-23 improved GND-stiching and some tracks width
    [SDBox-mini.kicad_pcb]
2021-07-23 modified footprint
2021-07-23 silkscreen fix
    [SDBox-mini.kicad_pcb]
2021-07-24 added silkscreen texts and oshw-symbol
    [SDBox-mini.kicad_pcb]
2021-07-24 added schematic pdf
2021-07-26 Changed pin assignment BUSY from PB0 to PD4, POUT from PD4 to PD5 and rerouted due to change in FW.
    [SDBox-mini.kicad_pcb, SDBox-mini.sch]
2021-07-26 removed FTDI-header, added ICSP-header, removed hw-debounce circuit and rerouted
    [SDBox-mini.kicad_pcb, SDBox-mini.sch]
2021-07-26 Improved 3V3 and other small cosmetic fixes
    [SDBox-mini.kicad_pcb]
2021-07-27 removed transistor Q1, changed Activity LED circuit to sink by SS
    [SDBox-mini.kicad_pcb, SDBox-mini.sch]
2021-07-27 small via GND improvements
    [SDBox-mini.kicad_pcb]
2021-07-27 added decoupling cap near ICSP-header VCC and relabeled ordering of components
    [SDBox-mini.kicad_pcb, SDBox-mini.sch]
2021-07-27 improved GND-area around D6,D7-vias by better positioning
    [SDBox-mini.kicad_pcb]
2021-07-27 small fix Activity LED-return line
    [SDBox-mini.kicad_pcb]
2021-07-28 removed AREF capacitor, it was unnecessary
    [SDBox-mini.kicad_pcb, SDBox-mini.sch]
2021-07-28 changed Activity-LED to be controlled by PB0, added 10k pull-up resistor on SS-line
    [SDBox-mini.kicad_pcb, SDBox-mini.sch]
2021-07-28 Removed capacitor at VCC-pin ICSP-header and renumbered Caps
    [SDBox-mini.kicad_pcb, SDBox-mini.sch]
2021-07-28 Changed U4 to a 74LVC1G17 and made SOT-353_SC-70-5_Custom_Handsoldering footprint
    [SDBox-mini.kicad_pcb, SDBox-mini.sch]
2021-07-28 adapted TSSOP-8_3x3mm_P0.65mm footprint for Handsoldering
    [SDBox-mini.kicad_pcb, SDBox-mini.sch]
2021-07-29 added optional pull-up on MOSI, fixed keep-out area of copper pour on U3,U4 GND-pads to neighbouring pad
    [SDBox-mini.kicad_pcb, SDBox-mini.sch]
2021-07-30 added common pull-up for DAT1,DAT2-lines (pin 8 and 1) on MicroSD-connector-pads
    [SDBox-mini.kicad_pcb, SDBox-mini.sch]
2021-07-30 added a 10k resistor pack and set individual pull-ups for DAT1,DAT2-lines (pin 8,1)
    [SDBox-mini.kicad_pcb, SDBox-mini.sch]
2021-08-01 update schematic pdf
2021-08-04 Fixed peg holes to 1.2 mm
2021-08-04 Fixed to oval holes and increased from 0.65 mm to 1 mm in y-direction, accomodates 0.7mm pegs
2021-08-04 cleanup of lib symbols and pcb silkscreen text
    [SDBox-mini.kicad_pcb, SDBox-mini.sch]
2021-08-04 update of schematic pdf
2021-08-10 Silkscreen fix marking ICSP pin 1
    [SDBox-mini.kicad_pcb]
2022-05-31 Replaced U4 (74LVC1G17) with 74AHCT1G126 (same footprint), added pull-up resistor with 2.0mm two-pin-jumper for tristate MISO high-Z when flashing new fw
    [SDBox-mini.kicad_pcb, SDBox-mini.sch]

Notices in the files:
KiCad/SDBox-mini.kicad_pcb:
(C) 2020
